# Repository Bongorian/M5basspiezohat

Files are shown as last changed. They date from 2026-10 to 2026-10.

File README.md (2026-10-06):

# M5basspiezohat

M5StickS3のHat2に接続する、ベース用の5チャンネル・ピエゾ入力基板。弦ごとの独立したピエゾ信号を高入力抵抗のバッファと音声ADCで処理し、TDMで本体へ送る。

本体で音程検出とUSB MIDI出力を行うESP-IDFファームウェアを含む。基板とファームウェアは実機未検証のR1試作版。

```text
独立ピエゾ ×4〜5 → 保護・バッファ・LPF → ES7210 ×2
                                      → TDM → M5StickS3
                                               → 音程検出・USB MIDI
```

## 仕様

| 項目 | R1 |
| --- | --- |
| 接続先 | M5StickS3 Hat2 |
| 入力 | 独立ピエゾ最大5チャンネル、内部SIG/GNDはんだパッド |
| ADC | ES7210×2、TDMカスケード接続 |
| 電源 | Hat2 EXT_5V、基板内でアナログ／デジタル3.3Vを生成 |
| 基板 | 21×38×1.0mm、4層、四隅R1mm |
| 実装 | 表面PCBA 101点。裏面は裸銅箔テストパッド4点 |
| 手実装 | ヘッダJ6、ピエゾ配線 |
| 筐体の設計範囲 | Hat単体・コネクタ込み48×24×15mm以内 |

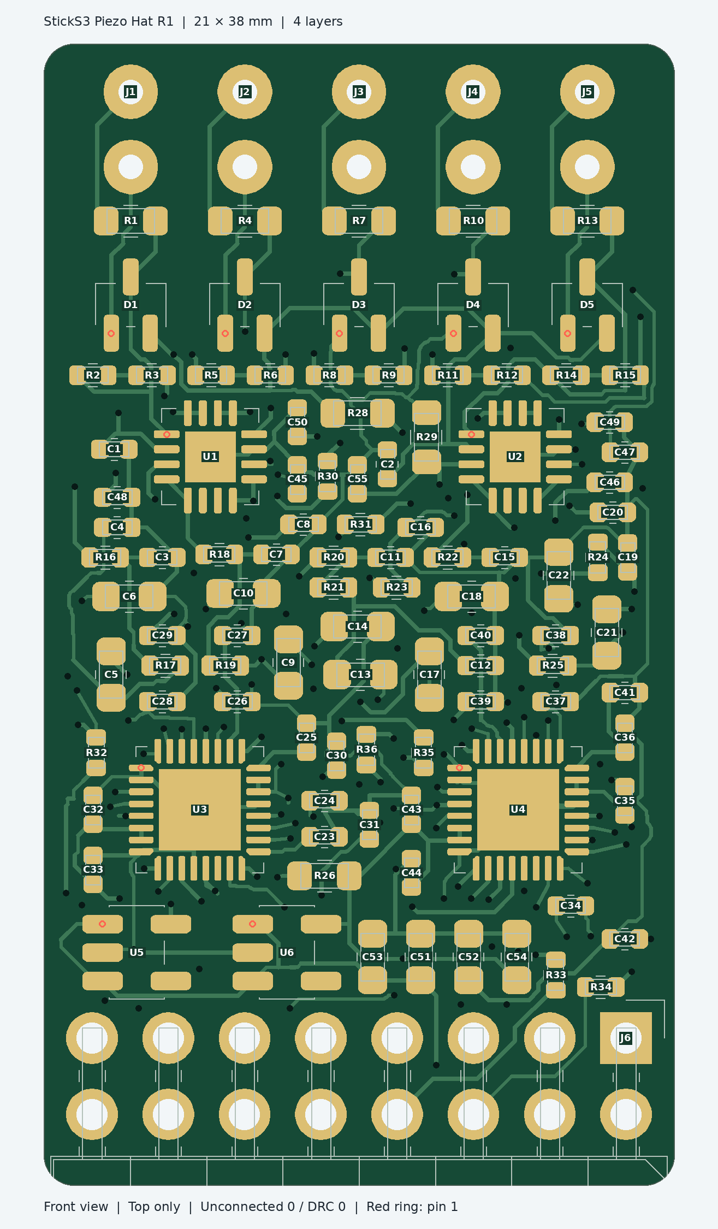
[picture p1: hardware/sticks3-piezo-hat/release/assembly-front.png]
部品位置とピン1


## 設計データの利用

1. [基板仕様・接続表](hardware/sticks3-piezo-hat/README.md)で電源、Hat2端子、ピエゾ入力を確認する。
2. KiCad 9で [プロジェクト](hardware/sticks3-piezo-hat/sticks3-piezo-hat.kicad_pro)を開く。[回路図](hardware/sticks3-piezo-hat/sticks3-piezo-hat.kicad_sch)と[配線済み基板](hardware/sticks3-piezo-hat/sticks3-piezo-hat.kicad_pcb)が編集元。
3. 製造には [JLCPCB用データ一式](hardware/sticks3-piezo-hat/release/PCBA_JLCPCB.zip)と[製造・組立手順](hardware/sticks3-piezo-hat/manufacturing.md)を使用する。BOM、CPL、手実装部品の一覧を含む。
4. 変更後は[再生成・検査手順](hardware/sticks3-piezo-hat/README.md#ソースと再生成)に従い、製造データを再出力する。
5. [ファームウェアの導入・操作手順](firmware/README.md)に従ってM5StickS3へ書き込み、入力スロットを確認する。標準は5弦・共通MIDIチャンネル1・起動時ミュート・高速開始設定。[標準設定の書き込み用ZIP](firmware/release/m5basspiezohat-sticks3-0.2.1.zip)も使用できる。

## 検証状況

KiCad 9.0.9で未接続0件、DRC違反0件、ERC違反0件。回路図・基板・設計マニフェストの318接続を照合済み。[検査記録](hardware/sticks3-piezo-hat/validation.md)を参照。

Hat2ヘッダの嵌合、TDM取得、Low Bまでの周波数応答、弦間の振動漏れ、音程検出の遅延は未検証。[ファームウェア設計・評価手順](docs/firmware-design.md)に取得条件と評価項目を記載している。標準のUSBデバイスモードはUSBホストへ接続する。ホストモードも実装しているが、StickS3はUSB-Cへ給電しないため、音源側への外部VBUS給電と適切な接続回路が必要。

ファームウェアはESP-IDF v5.4.2でESP32-S3向けビルドを確認。合成信号による音程・発音・MIDIルーティングのホストテストを通過している。[CI](https://github.com/Bongorian/M5basspiezohat/actions/workflows/firmware.yml)でもビルドとテストを実行する。

[クロストーク分離・校正学習の検討](docs/crosstalk-separation.md)には固定行列とFIR分離の導入条件を記載。同期CSVから固定混合行列を学習するオフライン評価ツールを含む。リアルタイム分離と実機学習は未実装。

[Grove接続の外付けUSB MIDIホスト案](docs/grove-usb-midi-host.md)に、別USB端子を追加して本体USB-Cを維持する構成、通信・給電条件、LCSC部品候補を記載している。外部基板は未製作。

[筐体モデル](mechanical/sticks3-hat-concept.md)は寸法・保持構造の検討用。蓋と下端受けの固定方法、ケーブル出口は未設計。

## ファイル構成

| ディレクトリ | 内容 |
| --- | --- |
| `hardware/sticks3-piezo-hat/` | KiCad編集元、プロジェクト内ライブラリ、BOM、生成・検査ツール |
| `hardware/sticks3-piezo-hat/release/` | Gerber、PCBA用BOM/CPL、組立位置図、製造用ZIP |
| `mechanical/` | Blender筐体検討モデル、寸法計算、生成スクリプト |
| `docs/` | ファームウェア設計と評価手順 |
| `firmware/` | ESP-IDFアプリ、音程検出、USB MIDI、診断ツール、ホストテスト、書き込み用ZIP |

## ライセンス

KiCad由来のライブラリ・モデルとファームウェア依存ライブラリの出典・ライセンスは [NOTICE.md](NOTICE.md) を参照。プロジェクト独自部分の利用ライセンスは未指定。

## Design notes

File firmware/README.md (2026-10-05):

# M5StickS3 firmware

M5basspiezohat R1の5入力をES7210×2からTDM/DMAで取得し、弦別の音程をUSB MIDI 1.0へ変換するESP-IDFアプリケーション。M5StickS3専用。実機でのADCカスケード取得・音源発音・処理速度は未検証。

## 実装内容

- 16kHz、8スロット、16bitのTDM受信。32フレーム単位、DMA 8バッファ。
- ES7210のI²C初期化、チップID・設定・動作状態の読み戻し。
- 4／5弦の独立解析。DC除去、63タップFIR、4kHzへの間引き、YIN音程推定。
- Note On／Off、入力強度に応じたVelocity、再ピッキング。弦別チャンネル時は任意で±2半音Pitch Bend。
- USB MIDIとUSB CDC診断の複合デバイス。液晶表示、ボタン操作、入力スロット変更。
- USB MIDIホスト送信。モードをNVSへ保存し、再起動でデバイス／ホストを切り替える。
- USB再接続、DMA欠損、送信キュー不足時のAll Sound Offと解析履歴のクリア。
- 発音開始は短い観測＋4ms更新、持続音は長い観測＋8ms更新。弦ごとの判定時刻を分散し、USBホストでは複数イベントをまとめて送信する。

## 標準設定

| 項目 | 値 |
| --- | --- |
| 本体 | M5StickS3、ESP32-S3、Flash 8MB／OPI PSRAM 8MB |
| ピエゾ入力 | J1〜J5 = B0／E1／A1／D2／G2、MIDIノート23／28／33／38／43 |
| TDM | DSP A、1 BCLK幅WS、1 bit遅延、8×16bit |
| クロック計算値 | MCLK 4.096MHz、BCLK 2.048MHz、WS 16kHz |
| 入力スロット | J1〜J5 = 0〜4。実基板で確認・修正が必要 |
| ADC PGA | 0dB |
| 発音／停止ゲート | 正規化RMS 0.004／0.002 |
| MIDI | 全弦をチャンネル1へ送信、Pitch Bendなし |
| 起動 | ミュート。確認後に `arm` またはAボタンで発音開始 |
| 音程追従 | 高速開始設定を有効。持続音は長い観測へ戻す |

USB-Cは標準でMIDI**デバイス**として動作する。PC、USB MIDIホスト、USBホスト端子のある音源へ接続する。通常のUSBデバイス端子だけを持つ音源へ接続する場合は、後述のホストモードと外部VBUS給電を使用できる。DIN MIDI出力は搭載していない。デバイスモードのUSB VID/PIDは開発用設定 `303A:4001`。

## USBホスト／デバイス切り替え

`role host` またはBボタン2秒長押しでミュートし、設定保存後に再起動する。B長押しは現在の役割を反転する。次回起動でも保存したモードを使う。デバイスモードでは `role device` も指定できる。モード切り替えはホットスワップではない。

**StickS3本体はUSB-CへVBUSを供給しない。** 本体回路図のUSB電源は入力経路で、固定したM5Unified v0.2.25の `setUsbOutput` はStickS3では動作しない。ホストモードには、音源のUSB端子へ5Vを供給し、StickS3側への逆流を防止できる外部給電アダプタなどの適切な接続回路が必要。電源をつないだだけのYケーブルや、動作が不明なハブは前提にしない。本体と音源の電源条件、Type-Cの役割・CC条件も接続機器に合わせて確認する。ソフトウェアのホスト切り替えだけでバス給電型音源へ直結できることを意味しない。[本体資料・回路図](https://docs.m5stack.com/en/core/StickS3#schematics)

公開回路図ではCC1／CC2に5.1kΩの固定プルダウン（R3／R4）がある。ファームウェアはこの抵抗を切り替えられず、USB-CのDRP／電力役割の切り替えは実装しない。ホストPHYで通信できることと、Type-Cポートが適切なホスト接続を構成できることを分けて評価する。外部接続回路はVBUSだけでなくCC条件も満たす必要があり、一般的なUSB-Cケーブルでの音源直結は保証しない。

ホストはFull-Speedのクラス準拠USB MIDI 1.0、最初の設定のalternate setting 0、最初の対応するbulk OUT、cable 0へ送信する。複合デバイス内のMIDIインターフェースにも対応する。MIDI 2.0専用、独自ドライバ必須、複数音源・ハブ、多ケーブル選択、MIDI受信は対象外。MIDI端子のあるUSB音源・USB MIDIインターフェースを外部デバイスとして接続する。[ESP-IDFホスト仕様](https://docs.espressif.com/projects/esp-idf/en/v5.4.2/esp32s3/api-reference/peripherals/usb_host.html)

ホストモード中は同じUSB-CでPCへCDC診断を提供できない。LCDに `HOST` と接続状態を表示する。Aクリックで発音切替、Aを1秒長押しで固定ノート試験、BクリックでPanic、Bを2秒長押しでデバイスモードへ戻る。USBは対応音源の列挙・初期Panic完了後に `ready` となる。

復旧時はAを押したままリセットすると、その起動を強制デバイスモードにできる。保存モードは変更しないため、CDCから `role device` で保存する。書き込みが必要なら本体のROMダウンロードモードを使う。PCへの接続前にデバイスモードへ戻す。

切断・再接続で解析状態をクリアする。転送異常や1秒以上応答しない音源では送信を停止し、再接続を要求する。ケーブル断や応答不能で届かないNote Offはソフトウェアで保証できないため、音源側の停止操作も利用する。ホストの給電と実機の列挙・発音は未検証。

## ビルド

LinuxでGit、Python 3、CMake、NinjaとESP-IDFの[インストール前提パッケージ](https://docs.espressif.com/projects/esp-idf/en/v5.4.2/esp32s3/get-started/linux-macos-setup.html)を用意する。リポジトリのルートから実行する。

```sh
bash firmware/tools/setup.sh
bash firmware/tools/build.sh
```

既にESP-IDF v5.4.2がある場合は、その `export.sh` を読み込んでから `build.sh` を実行できる。ローカルの `firmware/.tools/esp-idf` がある場合はそちらが優先される。setupはSDKのコミットを検査する。ライブラリの版と取得ハッシュは `main/idf_component.yml` と `dependencies.lock` に固定している。

```sh
bash firmware/tools/build.sh menuconfig
```

`M5basspiezohat` メニューで弦数、スロット、ゲート、PGA、MIDIチャンネル、弦別チャンネル、Pitch Bend、起動ミュート、TDM形式を設定する。4弦設定はJ1〜J4=E1／A1／D2／G2。弦別チャンネルは基本チャンネルから連続して使用し、最後が16を超える設定では発音しない。スロット重複、停止ゲート以上に低い発音ゲートも無効設定となる。

`Short startup observation and 4 ms initial pitch update`（`CONFIG_BASS_FAST_TRACKING`）は標準で有効。無効にすると発音開始から長い観測＋8ms更新を使う。どちらも確信度0.85と2回の安定判定を維持する。計算処理の最適化は両設定で有効。比較値と実機での確認条件は [処理時間と発音遅延](performance.md) を参照。

TDM形式のPhilipsはカスケード評価用の別設定。スロットの並びも変わり得るため、形式を変更したら全入力を再確認する。任意のチューニングは `main/board.hpp` の `open_notes` を変更する。

## 書き込み

書き込みは既存の本体ファームウェアとパーティションテーブルを置き換える。M5StickS3をUSBでPCへ接続し、OSが割り当てたポートに置き換える。

```sh
bash firmware/tools/build.sh -p /dev/ttyACM0 flash
```

接続できない場合は本体のダウンロードモードへ入れて再試行する。起動後は複合USBデバイスへ切り替わるため、CDCポート番号が変わる場合がある。[本体の公式資料](https://docs.m5stack.com/en/core/StickS3)も参照。

`release/m5basspiezohat-sticks3-0.2.1.zip` は高速開始設定を含む標準設定でのビルド済みファームウェア。0.1.0と0.2.0のZIPも比較用に保持する。展開先でPython環境に `esptool==4.9.0` を導入し、次のように書き込める。ブートローダ、パーティション、アプリをそれぞれ指定し、NVS領域の一括消去は行わない。

```sh
python -m esptool --chip esp32s3 --port /dev/ttyACM0 --baud 460800 write_flash \
  --flash_mode dio --flash_freq 80m --flash_size 8MB \
  0x0 bootloader/bootloader.bin \
  0x8000 partition_table/partition-table.bin \
  0x10000 m5basspiezohat.bin
```

ビルド済みZIPの `BUILD_INFO.json` にSDK・設定・SHA-256を記録している。自前ビルドのパッケージ化は `python3 firmware/tools/package.py`。

## 初回確認

1. 電源を切ってHat2とピエゾを接続する。[接続表](../hardware/sticks3-piezo-hat/README.md#hat2接続)に従う。
2. USBで起動し、LCDの `MUTED` とADC状態を確認する。ADC異常時もUSB診断と固定ノート試験は使用できる。
3. USB MIDIホスト側で `M5basspiezohat R1` を選び、音源をMIDIチャンネル1に設定する。
4. CDC端末から `test` を送る。ノート36、Velocity 80を300ms発音し、ピエゾからの発音はミュートする。
5. `slots` を観測し、J1〜J5へ順番に既知の信号を入力する。各入力に対応する0〜7のスロットを特定する。ピエゾ弦間の機械的漏れがある場合は、入力パッドへの電気信号で確認する。
6. 例えば対応が6／3／0／7／2なら `map 6 3 0 7 2`。続けて `status` で反映を確認する。`map` はミュートする。変更はRAM上のみなので、常用値はmenuconfigへ保存して再ビルドする。
7. `arm` またはAボタンで発音を開始する。無音でNote Off、各弦の開放音、同時発音を確認する。Aでミュート切替、BでミュートとPanic。

標準の共通チャンネルでは、複数弦の同じノートを1音として保持し、最後の弦が停止したときにNote Offを送る。その間の同じ音の再アタックは統合される。弦ごとの同音再発音やPitch Bendが必要なら、弦別チャンネルを有効にし、音源の受信チャンネルを揃える。Pitch Bend時はRPNで±2半音を設定する。

## 診断

CDCは115200設定の改行区切りASCIIコマンド。USB MIDIと同時に利用できる。Python補助ツールは `python3 -m pip install -r firmware/tools/requirements.txt` で依存を導入する。

```sh
python3 firmware/tools/console.py /dev/ttyACM0 status
python3 firmware/tools/console.py /dev/ttyACM0 slots --watch
python3 firmware/tools/console.py /dev/ttyACM0 map 6 3 0 7 2
python3 firmware/tools/console.py /dev/ttyACM0 arm
```

| コマンド | 内容 |
| --- | --- |
| `help` | コマンド一覧 |
| `status` | ADC／USB状態、ミュート、欠損、最大DSP処理時間、空きRAM、弦別音程・確信度・クリップ数 |
| `slots` | 全8スロットのRMSと直近ブロックのピーク |
| `adc` | 両ADCの主要レジスタ読み戻し |
| `map S1 S2 S3 S4 [S5]` | J1から順にスロットを指定。重複不可 |
| `arm` | ADCと設定が正常なら発音開始 |
| `mute`／`panic` | 発音停止とAll Sound Off／All Notes Off |
| `test` | 設定した基本チャンネルで固定ノート36を発音。A長押しでも実行 |
| `role [host\|device]` | USB役割の確認／NVS保存と再起動 |

`dma_ovf`、`queue_drop`、`read_err`、`midi_drop`、`gaps` が増加しないことを確認する。`queue_peak` は取得キューからブロックを取り出した直後の最大待ちブロック数で、1ブロックは2ms。最大処理時間だけで平均負荷は判断しない。`dsp_us`／`max_dsp_us` は音程処理とスロット診断の経過時間を測り、タスクの割り込みを含み得る。共有状態の更新・USB・LCDの時間は含まない。`dsp_us` の増分を観測時間と比較し、10分以上の連続取得で欠損を調べる。状態の公開は16msごと。`clips` が増える場合はPGAを下げ、入力振幅と前段回路を確認する。

## 検証と制約

ホストテストは合成信号を使用し、Low B〜G4、倍音優勢波形、5入力同時検出、無音、DC、ノイズ、クリップ、任意サイズの受信ブロック、Velocity、Pitch Bend、再ピッキング、スロット変更、送信失敗、同音の共有とチャンネル割り当てを確認する。

```sh
cmake -S firmware/tests -B firmware/build-host -G Ninja
cmake --build firmware/build-host
ctest --test-dir firmware/build-host --output-on-failure
```

標準でAddressSanitizer／UndefinedBehaviorSanitizerを有効にする。GitHub ActionsでもホストテストとESP32-S3ビルドを実行する。

標準設定の合成開放音では、入力開始から最初のNote OnまでB0=64ms、E1=48ms、A1=40ms、D2=32ms、G2=28ms分のサンプルを使用した。これは各弦を単独の1入力設定で評価した結果で、5入力時は弦ごとに判定位相が異なる。ADC・USB・音源遅延と実機のCPU処理時間を含まない。演奏時の遅延保証ではない。

実機ではADCのリビジョン、8スロットの出力順、クロック、低域HPF、USBの両役割、CPU余裕、弦間漏れを確認する必要がある。レジスタの読み戻しが成功しても音声フレームの正しさは保証されない。USB役割だけをNVSへ保存し、スロット・ゲート・ゲインはビルド設定で管理する。OTAは実装していない。

弦間クロストークは [分離・校正学習の検討](../docs/crosstalk-separation.md) を参照。同期CSVから固定混合行列を学習するオフライン評価ツールと合成テストを収録している。リアルタイム分離・本体での学習・校正波形のUSB出力は未実装。

詳細は [実装設計・評価手順](../docs/firmware-design.md) と [依存ライブラリの出典](../NOTICE.md) を参照。

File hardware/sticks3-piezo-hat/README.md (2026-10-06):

# M5basspiezohat R1 — 基板仕様

弦ごとに独立したピエゾを最大5入力受け、ES7210×2のTDM出力をM5StickS3へ渡す。[付属ファームウェア](../../firmware/README.md)が音程検出とUSB MIDI出力を行う。基板・ファームウェアとも実機未検証。

**筐体の設計範囲：Hat単体・コネクタ込み48×24×15mm以内。** 基板は21×38×1.0mm、四隅R1mm、4層。ケース本体41.1×23.8×14.8mm。候補ヘッダC53207371のメーカー図面に基づくコネクタ込み公称長47.3mm、公差予算込み47.9mm。実機嵌合・造形精度は未確認で、寸法保証ではない。基板に固定穴・切り欠きはなく、筐体の左右ガイド溝と上下の受けで支える機構案。受けと蓋の留め方は未設計。[機構案](../../mechanical/sticks3-hat-concept.md)を参照。

## 設計検査

KiCad 9.0.9で未接続0件、DRC違反0件、回路図ERC違反0件。配線済み基板は [sticks3-piezo-hat.kicad_pcb](sticks3-piezo-hat.kicad_pcb)。2410配線セグメント／161ビア、回路図／基板／設計マニフェストの318接続が一致。部品本体は表面のみ、裏面はTP1〜4の裸銅箔。内層GND面の信号線は0、SMDパッドとビア穴の重なりは0。

[JLCPCB用データ一式](release/README.md)：[Gerber ZIP](release/Gerber_JLCPCB.zip)、[PCBA BOM](release/BOM_JLCPCB.csv)、[CPL](release/CPL_JLCPCB.csv)、[組立位置図](release/assembly-front.png)。BOMとCPLは101個の部品名が完全一致し、全点Top。CPLは品番別の回転補正を適用済み。D1〜D5もPCBA対象。J6とピエゾ線は手実装。U4の割り込み出力（13番ピン）はNC。ADC初期設定では割り込みを無効にする。

最小配線幅／間隔0.10／0.10mm、貫通ビア外径0.40mm・穴0.20mm、表裏テント、マスク開口1:1。[JLCPCBの能力表](https://jlcpcb.com/capabilities/pcb-capabilities)に対応するが、外径0.45mm未満・穴0.20mmのビアは追加料金対象なので、注文時に小径ビアの条件を指定する。製造条件と手実装の手順は [manufacturing.md](manufacturing.md)、検査記録は [validation.md](validation.md) を参照。

## 回路

| 回路 | 仕様 |
| --- | --- |
| 入力 | SIG/GND ×5組、内部はんだパッド、穴0.8mm・径1.8mm |
| 保護 | 47kΩ直列＋低漏れBAV199Wの2ダイオードクランプ |
| 入力負荷 | 10MΩを2個直列にした20MΩでVMIDへバイアス |
| バッファ | TLV9064IRTER ×2、3×3mm WQFN、利得1 |
| 中点 | 47kΩ分圧＋1µF→U2Bバッファ、約1.65V |
| LPF | 各入力1kΩ／47nFを2段、受動回路 |
| ADC結合 | P側10µF直列、N側10µFでAC接地。ADCのDCバイアスを分離 |
| ADC | ES7210 ×2、入力8スロット、うち5スロットを音程解析 |
| 電源 | EXT_5V→AP2112K-3.3 ×2、3V3A／3V3D |
| クロック | MCLK/BCLK/WSに33Ω、データ／カスケードにも33Ω |

受動LPFは2段の間にバッファがないため、独立したRCを2個掛けた特性と異なる。ADC入力負荷を無視した等しいR/Cの伝達は `1/(1+3sRC+(sRC)^2)`、合成-3dB周波数は約1.27kHz。R=1kΩ、C=47nFによる計算値で、ADC入力インピーダンスを含む実際の応答は測定する。アタックと倍音を残せるか、ADC内PGA・HPFと合わせて確認する。

Low B・30.87Hzを保つため、ピエゾ容量、20MΩ負荷、AC結合容量、ADC内部HPFをまとめて評価する。低漏れ保護の代わりに汎用BAV99や漏れの大きいSchottkyへ無確認で置き換えない。高抵抗入力付近は組み立て後にフラックスを清掃する。無給電時のピエゾ電圧による電源への回り込みも試験する。

## LCSC部品と実装分担

| 部品 | LCSC | 個数 | 分担 |
| --- | --- | ---: | --- |
| ES7210・4入力ADC | [C365743](https://www.lcsc.com/product-detail/C365743.html) | 2 | PCBA |
| TLV9064IRTER・3×3mm WQFN | [C882406](https://www.lcsc.com/product-detail/C882406.html) | 2 | PCBA |
| AP2112K-3.3TRG1 | [C51118](https://www.lcsc.com/product-detail/C51118.html) | 2 | PCBA |
| BAV199W・CBI・SOT-323 | [C51315120](https://www.lcsc.com/product-detail/C51315120.html) | 5 | PCBA |
| 10MΩ・SAE・0402 | [C54531017](https://www.lcsc.com/product-detail/C54531017.html) | 10 | PCBA |
| 1kΩ・0402 | [C11702](https://www.lcsc.com/product-detail/C11702.html) | 12 | PCBA |
| 33Ω・0402 | [C25105](https://www.lcsc.com/product-detail/C25105.html) | 5 | PCBA |
| 47kΩ・0603 | [C25819](https://www.lcsc.com/product-detail/C25819.html) | 8 | PCBA |
| 100nF・0402 | [C1525](https://www.lcsc.com/product-detail/C1525.html) | 6 | PCBA |
| 47nF・0402 | [C82219](https://www.lcsc.com/product-detail/C82219.html) | 10 | PCBA |
| 1µF・0402 | [C52923](https://www.lcsc.com/product-detail/C52923.html) | 25 | PCBA |
| 10µF・0603 | [C19702](https://www.lcsc.com/product-detail/C19702.html) | 14 | PCBA |
| 2×8・2.54mm L型ヘッダ・BXCONN | [C53207371](https://www.lcsc.com/product-detail/C53207371.html)・候補、実機嵌合未確認 | 1 | 手はんだ |
| ピエゾ線 | 基板内パッドへ接続 | 5組 | 手はんだ |

部品番号・数量・実装分担は [BOM_full.csv](BOM_full.csv) を基準とする。PCBAには [BOM_JLCPCB.csv](BOM_JLCPCB.csv)、手実装には [HAND_ASSEMBLY.csv](HAND_ASSEMBLY.csv) を使用する。LCSCの販売在庫とJLCPCBの実装用在庫・部品区分・調達価格は個別に確認する。

## Hat2接続

J6番号は **M5の外部Hat2端子表の番号**。M5内部回路図のCN2番号とは異なる。

| J6 | M5信号 | 本基板 |
| ---: | --- | --- |
| 1 | GND | GND |
| 2 | G5 | SCL |
| 3 | EXT_5V | 5V_HAT |
| 4 | G4 | SDA |
| 6 | G6 | WS |
| 7 | G1 | MCLK |
| 8 | G7 | BCLK |
| 9 | G8 | TDM DATA |
| その他 | BOOT/BAT/3V3/5VIN等 | 未接続 |

この番号とGPIOは [M5公式端子表](https://docs.m5stack.com/en/core/StickS3) に基づく。標準ヘッダのピン1マークと本体のGND位置は、選定した部品の視方向と実物で照合する。嵌合と挿入長は実機で確認する。

`M5.begin()`後、`M5.Power.setExtOutput(true)`でEXT_5Vを出力にする。本体GPIOは3.3V。EXT_5Vを出力にした状態で、その端子へ別電源を接続しない。

ADCの7bit I²CアドレスはU3＝0x40、U4＝0x41を想定したAD0/AD1接続。アドレスは実機で確認する。U3 TDMOUT→33Ω→U4 TDMIN、U4 TDMOUT→33Ω→J6 DATA。共通MCLK/BCLK/WSを使う。レジスタ設定は実機試験で確定する。

## 取得・MIDIの初期条件

16kS/s、8スロット×16bit、MCLK4.096MHz、BCLK2.048MHzを評価開始点とする。DMAは32フレーム×8本、合計4096B／16ms容量。2msごとに取得し、解析側へ渡す。詳細は [ファームウェア設計](../../docs/firmware-design.md) を参照。

Low Bの周期は約32.4ms。DMA待ちを短くしても、音程確定に必要な観測時間は残る。音声取得、音程解析、USB送信、音源発音の遅延を分けて測定する。USB MIDIは本体USB-Cを使い、音源のUSBホスト機能またはPC／USB MIDIホストを経由する。DIN出力回路はこのHatには載せていない。

## ソースと再生成

- `sticks3-piezo-hat.kicad_sch`：全ピンを明示した回路図
- `sticks3-piezo-hat.kicad_pcb`：配線済み最終基板
- `sticks3-piezo-hat-placement.kicad_pcb`：再生成用の配置版
- `PiezoHat.pretty/`、`PiezoHat.kicad_sym`：プロジェクト内ライブラリ
- `design.json`：ピン、型番、部品座標
- `BOM_JLCPCB.csv`：PCBA部品のみ、標準4列
- `jlc-rotation-corrections.json`：品番別のCPL回転補正。新しい品番へ変更したらプレビューを再確認
- `BOM_full.csv`、`HAND_ASSEMBLY.csv`：全調達／手実装
- `verify.py`、`verification.json`：接続と実装面の確認
- `preview/routed-front.png`、`preview/routed-board.glb`：最終基板の配線図・3D
- `release/`：Gerber、BOM、CPL、組立位置図、検査記録
- [ケースモデル](../../mechanical/sticks3-hat-concept.md)

KiCad 9.0.9の`kicad-cli`と`pcbnew`を読み込めるPythonが必要。Ubuntuでは`/usr/bin/python3`を使う。生成にはNumPy、図の出力にはPillow、補助ルータにはSciPyとC++17コンパイラを用意する。自動配線には別途`freerouting-cli`が必要。

```sh
cd hardware/sticks3-piezo-hat
/usr/bin/python3 generate.py
kicad-cli sch export netlist --format kicadxml -o schematic.xml sticks3-piezo-hat.kicad_sch
/usr/bin/python3 verify.py sticks3-piezo-hat-placement.kicad_pcb
/usr/bin/python3 route_compact.py sticks3-piezo-hat-placement.kicad_pcb NEW-routed.kicad_pcb
```

再生成は配置・回路図・BOMを上書きし、配線済み基板は別ファイルに保存する。KiCadのDSN出力へは0.127mm標準配線／0.10mm間隔、ビア径0.40mm・穴0.20mmを明示的に反映する。内層1はGND面、内層2は信号。QFN露出パッドの未充填ビアを禁止する。

## 組立・評価

[製造・組立手順](manufacturing.md)に従い、手実装部品とヘッダ方向を確認する。評価では電源・中点電圧、I²Cアドレス、ADC1個のTDM取得、2個のカスケード取得の順に確認する。ピエゾ接続後、Low Bの周波数応答、強いアタックでのクリップ、弦間漏れを測定する。

## 参照資料

メーカー資料：[ES7210レジスタ資料](https://files.waveshare.com/wiki/common/ES7210_DS.pdf)、[TLV9064](https://www.ti.com/lit/ds/symlink/tlv9064.pdf)、[CBI BAV199W](https://datasheet.lcsc.com/datasheet/pdf/08d81ae9ee2012e6b42c6110d851602f.pdf?productCode=C51315120)、[Espressif I²S/TDM/DMA](https://docs.espressif.com/projects/esp-idf/en/stable/esp32s3/api-reference/peripherals/i2s.html)。

## 製造データの再出力

リポジトリルートから実行する。配線済み基板を入力に、DRC／ERC・接続照合後、Gerber・BOM・CPL・ZIP・チェックサムを再出力する：

```sh
cd hardware/sticks3-piezo-hat
/usr/bin/python3 release.py
```

## 補助ルータ

`finish_route.py`用の補助ルータは `hardware/sticks3-piezo-hat/` で次のように構築する。生成・配線ツールは検討用で、毎回DRC／ERCと接続照合を行う。

```sh
mkdir -p .build
g++ -O3 -std=c++17 finish_astar.cpp -o .build/piezo-finish-astar
```

プロジェクト内のKiCad由来ライブラリについては [ライセンス文書](KICAD_LIBRARIES_LICENSE.md) と [出典](../../NOTICE.md) を参照。

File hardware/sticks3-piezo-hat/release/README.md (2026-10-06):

# M5basspiezohat R1 — 製造・組立手順

実機未検証の試作基板。製造データはKiCad 9.0.9で未接続・DRC・ERC各0件、回路図・基板・設計マニフェスト318接続の照合済み。PCBAは101点、全点Top。

## 製造ファイル

`hardware/sticks3-piezo-hat/release/` に次のファイルを格納している。`PCBA_JLCPCB.zip` は製造用データの一式。

| ファイル | 用途 |
| --- | --- |
| `Gerber_JLCPCB.zip` | 4層銅箔、表裏マスク、表面ペースト、表裏シルク、外形、PTH／NPTHドリル、Gerberジョブ |
| `BOM_JLCPCB.csv` | PCBA用のLCSC部品番号・参照名 |
| `CPL_JLCPCB.csv` | 101点の配置座標・回転、単位mm、Topのみ |
| `rotation-audit.csv` | KiCad角度・JLC補正値・補正後角度・基板のピン1座標。座標はCPLと同じmm／左下原点 |
| `assembly-front.png` | 部品位置とピン1の照合図。赤いリングはピン1 |
| `HAND_ASSEMBLY.csv` | 手実装するヘッダ、ピエゾ配線 |
| `BOM_full.csv` | 全部品の数量と実装分担 |
| `manifest.json` | ZIP・BOM・CPL・組立図のSHA-256とファイルサイズ |

## 基板条件

| 項目 | 指定値 |
| --- | --- |
| 材質・層数 | FR-4、4層 |
| 外形・厚さ | 21×38mm、1.0mm、四隅R1mm |
| 銅厚 | 外層1oz、内層標準0.5oz |
| 層構成 | F.Cu／In1.Cu（GND）／In2.Cu（信号）／B.Cu |
| マスク・実装面 | 緑、表面PCBA |
| 最小配線幅・間隔 | 0.10mm／0.10mm |
| 外形から銅箔 | 0.5mm以上 |
| ビア | 貫通、外径0.40mm、穴0.20mm、表裏テント |
| マスク開口 | 銅箔パッドと1:1 |

SMDペースト領域とビア穴の重なりは0件。裏面はTP1〜TP4の裸銅箔で、実装部品はない。

JLCPCBでは穴0.20mm・外径0.45mm未満のビアに追加料金条件がある。注文時の [基板能力表](https://jlcpcb.com/capabilities/pcb-capabilities) と小径ビア設定を確認する。小型基板のパネル／治具条件は利用する実装サービスで確認する。

## PCBA発注

1. `Gerber_JLCPCB.zip`を読み込み、外形・4層・厚さ1.0mmと上記の基板条件を確認する。
2. 表面実装を選択し、`BOM_JLCPCB.csv`と`CPL_JLCPCB.csv`を読み込む。
3. 101点の参照名、Top面、LCSC品番、在庫、実装区分、調達価格を確認する。
4. `assembly-front.png`と配置プレビューを比較する。特にU1〜U6のピン1と回転、QFN露出パッドを照合する。
5. `HAND_ASSEMBLY.csv`の部品とピエゾ線を別途準備する。

LCSC販売在庫とJLCPCB実装用在庫は個別に確認する。D1〜D5を含む全SMD部品101点をPCBA対象とする。J6ヘッダとピエゾ線は手実装。D1〜D5のC51315120が部品照合で未登録／調達不可の場合は、欠品のまま確定せずJLCPCBの部品調達を設定する。同名のBAV199Wでもメーカー・内部結線・ピン配列を照合せず置き換えない。

## CPLの回転と実装確認

CPLへKiCadの角度をそのまま転記せず、`jlc-rotation-corrections.json`の品番別補正を適用する。Top面で `JLC角度 = (KiCad角度 + 補正) mod 360`。実装座標と基板上のパッド・配線は変更しない。

| 部品 | KiCad角度 | 補正 | CPL角度 | 基板上の向き（表面） |
| --- | ---: | ---: | ---: | --- |
| U1・U2 / C882406 | 0° | 0° | 0° | ピン1は左上側 |
| U3・U4 / C365743 | 0° | 270° | 270° | ピン1は左上側 |
| U5・U6 / C51118 | 0° | 270° | 270° | 左に3端子、右に2端子。ピン1は左上 |
| D1〜D5 / C51315120 | 90° | 270° | 0° | ピン1＝左下GND、2＝右下3V3A、3＝上のHI入力 |

U3〜U6の補正は旧CPLを読み込んだ配置画像の部品マーク・端子列と基板パッドの比較に基づく。D1〜D5は新規追加のため、SOT-323の基準姿勢に基づく補正を新しいJLCPCBプレビューで確認する。新品番・別メーカーへの置換では同じ補正が適用できるとは限らない。

アップロードには補正済み`CPL_JLCPCB.csv`を使う。`CPL_KiCad.csv`は未補正の検査用で、発注には使わない。新データのJLCPCBプレビュー／DFMはまだ確認していない。`assembly-front.png`の赤いリングは基板の実際の1番パッドを示す。JLCPCBの色付き点だけをピン番号と解釈せず、端子列・メーカーのピン配置と合わせて照合する。[JLCPCBの配置・向きの説明](https://jlcpcb.com/help/article/pcb-assembly-faqs-part-2)

## 手実装と通電前確認

1. PCBA済みのD1〜D5のBAV199W保護ダイオードがすべて実装され、組立図のピン番号と一致することを確認する。
2. J6ヘッダを取り付ける。C53207371の嵌合は未検証のため、M5StickS3実物で向き・挿入長を確認する。
3. J1〜J5のSIG／GNDへ弦別ピエゾ線を接続する。高抵抗入力部のフラックスを清掃し、線材への引張力を筐体側で受ける。
4. GND・EXT_5Vの端子位置、電源短絡、ダイオード方向を確認する。端子番号は外部Hat2端子表を基準にする。
5. 本体初期化後にEXT_5Vを有効化し、3V3A／3V3D・VMIDとI²Cアドレスを測定する。EXT_5Vの出力モードでは同端子へ別電源を接続しない。

## 動作評価

ADC単体取得から2個カスケード取得へ進み、スロット対応、Low Bの低域応答、クリップ回復、弦間漏れを測定する。U4の割り込み出力はNCのため、ADC初期設定で割り込みを無効にする。

音程検出・USB MIDIのESP-IDFファームウェアをリポジトリに収録。ビルドと合成信号テストは確認済み、実機は未検証。[導入・診断手順](https://github.com/Bongorian/M5basspiezohat/tree/main/firmware)に従って書き込み、入力スロットを確認する。標準はUSBデバイスで接続先にUSBホスト機能が必要。USBホストモードも搭載するが、StickS3はUSB-Cへ給電しないため、音源側への外部VBUS給電が必要。筐体モデルは寸法・保持構造の検討用で、固定部とケーブル出口は未設計。

接続表・評価条件は [M5basspiezohatリポジトリ](https://github.com/Bongorian/M5basspiezohat) の基板仕様とファームウェア設計を参照。

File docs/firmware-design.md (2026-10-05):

# ファームウェア実装・評価手順

M5StickS3用ESP-IDFアプリケーションは `firmware/` に収録している。[導入・操作手順](../firmware/README.md)を参照。ESP32-S3ビルドと合成信号のホストテストは確認済み。ADCカスケード、USB接続、演奏遅延、CPU負荷の実機測定は未実施。

## 信号経路

```mermaid
flowchart LR
  P[独立ピエゾ 4〜5入力] --> A[保護・バッファ・LPF・AC結合]
  A --> D[ES7210 ×2]
  D -->|8スロット TDM| M[I²S受信・DMA]
  M --> Q[32フレームの取得キュー]
  Q --> F[DC除去・FIR・4kHz間引き]
  F --> Y[弦別YIN・包絡線・発音状態]
  Y --> R[MIDIチャンネル割り当て]
  R --> U[USB MIDIデバイス]
  U --> H[接続先USBホスト・外部音源]
```

## 電源・クロック・ADC

M5Unified初期化では内蔵音声・IMU・RTCを無効にする。本体がM5StickS3と認識された場合だけ `M5.Power.setExtOutput(true)` でHat2 EXT_5Vを供給する。GPIOは3.3V。出力中のEXT_5Vへ別電源を接続しない。[M5StickS3資料](https://docs.m5stack.com/en/core/StickS3)

| 信号 | GPIO / アドレス |
| --- | --- |
| SDA / SCL | GPIO4 / GPIO5、外部I²Cポート1、100kHz |
| MCLK / BCLK / WS / DATA | GPIO1 / GPIO7 / GPIO6 / GPIO8、I²Sポート0 |
| U3 / U4 | 7bit I²C 0x40 / 0x41 |
| USB | 本体USB-C、ESP32-S3のネイティブUSB |

U3 TDMOUT→33Ω→U4 TDMIN、U4 TDMOUT→33Ω→Hat2 DATA。内蔵PMICのGPIO47／48のI²Cポート0と外部ADCバスは分離している。

I²S受信を有効にしてクロックを供給した後、両ADCのID、リビジョンを読み取り、初期化する。設定の読み戻しと120ms後の状態確認を行い、取得を再開して起動直後の64ブロックを破棄する。ADC異常時は取得タスクを開始せず、表示・USB診断・固定ノート試験を維持する。

### 主なADC評価設定

完全な設定表は [es7210.cpp](../firmware/main/es7210.cpp)。以下はES7210 Rev.21資料を基にしたカスケード評価設定で、実機のリビジョンと音声フレームを照合する必要がある。

| レジスタ | 値 / 用途 |
| --- | --- |
| 0x02 / 0x03 / 0x04 / 0x05 / 0x07 | C1 / 02 / 01 / 00 / 20、16kHz・256fs |
| 0x08 | 44、8入力・スレーブ・EQバイパス |
| 0x11 | 63、16bit DSP A。Philips選択時60 |
| 0x12 | U3=07、U4=03、カスケード・最終段指定 |
| 0x0C / 0x10 / 0x16 | 00、割り込み・DMIC・ALCを無効化 |
| 0x20〜0x23 | 0D、低速HPFと自動オフセット補正の評価値 |
| 0x43〜0x46 | 10＋PGA設定、初期0dB |
| 0x4B / 0x4C | 40、ADC/PGA有効、未使用MICBIAS停止 |

[ES7210 Rev.21資料](https://files.waveshare.com/wiki/common/ES7210_DS.pdf)、[EspressifのTDM例](https://github.com/espressif/esp-idf/blob/v5.4.2/examples/peripherals/i2s/i2s_codec/i2s_es7210_tdm/main/i2s_es7210_record_example.c)を参照。設定レジスタが読み戻せることと、カスケード音声が正しく整列することは別に検証する。入力パッドへ既知の周波数を順に与え、全8スロットを観測してJ1〜J5への対応を確定する。

## 取得・タスク

| 項目 | 実装値 |
| --- | ---: |
| 取得レート | 16kS/s |
| フレーム | 8スロット×16bit |
| クロック計算値 | BCLK 2.048MHz、MCLK 4.096MHz |
| 取得ブロック | 32フレーム、512B、2ms |
| DMA | 8バッファ、4096B、16ms容量 |
| 取得→解析キュー | 16ブロック、約8kB、最大32ms分 |
| MIDIイベントキュー | 128イベント |
| USB / 取得 / 解析タスク | Core0優先度6 / Core0優先度22 / Core1優先度17 |
| 表示 | 主タスク、200ms周期 |

DMA容量16msはブロック待ち時間2msとは異なる。取得キューは処理時間の変動を吸収するが、遅延を一定に保証しない。DMAオーバーフロー、取得エラー、ブロック連番の欠損、送信不足ではPanicを要求し、音程履歴・ノート所有情報をクリアする。USBの再接続時も設定チャンネルにCC120／123とPitch Bend中央値を送り、必要時だけRPNで±2半音を設定する。

受信タスクは解析を行わず、ブロックのコピーと連番を管理する。音程処理は取得とは別Coreで行う。USBのFIFO不足は4byteのMIDIパケットを保持して再送し、Panic前の古いイベントは世代番号で捨てる。ISRのオーバーフロー数はFreeRTOSのクリティカルセクションで保護する。[ESP-IDF I²S仕様](https://docs.espressif.com/projects/esp-idf/en/v5.4.2/esp32s3/api-reference/peripherals/i2s.html)

USBはNVSに保存した役割を起動時に読み込む。デバイスモードはTinyUSBのMIDI＋CDC、ホストモードはESP-IDF USB Host Libraryと専用MIDI OUTクライアントを使用する。同じ内蔵PHYへ両方のドライバを同時に入れず、役割変更時はミュートして保存・再起動する。Aを押したままリセットするとその起動だけデバイスモードを強制する。

ホストのライブラリ処理はCore0優先度5の別タスク。全クライアントAPIと転送完了処理は既存のUSB送信タスクで実行する。Full-Speed MIDI 1.0のalternate setting 0、最初のbulk OUT、cable 0を選ぶ。非対応記述子・不正長・MIDI 2.0専用インターフェースは拒否する。非同期転送を1件ずつ処理し、1秒のソフトウェア監視で無応答を停止・キャンセルする。切断時は完了コールバックを待ってから転送・インターフェース・デバイスを解放する。

USBホストでは4byteイベントをendpointの最大パケット長（最大64byte）までまとめ、USB送信タスクの巡回末尾で1転送として送る。別の転送が実行中なら次のバッチを保持する。バッチが満杯なら元のイベントを待たせ、順序を保持する。Panic／切断時は未送信バッチを破棄する。バッチ化はUSBホストの実機転送では未検証。

StickS3はUSB-CへVBUSを供給しないため、ホストでは外部の給電・逆流防止・Type-C役割条件を満たす接続が必要。ホスト時のCDCは提供しない。操作・制限は [USB切り替え手順](../firmware/README.md#usbホストデバイス切り替え) を参照。[USB MIDI 1.0仕様](https://www.usb.org/sites/default/files/midi10.pdf)、[ESP-IDFホストAPI](https://docs.espressif.com/projects/esp-idf/en/v5.4.2/esp32s3/api-reference/peripherals/usb_host.html)

外部音源との接続は、自己給電のクラス準拠USB MIDI音源と本体USBホストモードを基本構成とする。追加のUSBホストマイコンは不要。自己給電は音源の動作用電力をUSBから供給しないという条件であり、USB接続検出用VBUSやType-CのCC条件を省略できることを意味しない。接続回路でこれらを満たし、対象音源で列挙・Note On／Off・切断復帰を確認する。自己給電デバイスのVBUS監視については [EspressifのUSBデバイス仕様](https://docs.espressif.com/projects/esp-idf/en/v5.0.3/esp32s3/api-reference/peripherals/usb_device.html) を参照。

## 音程・発音

入力別DC除去（係数0.9995）→63タップHamming FIR（カットオフ900Hz）→4分の1間引きで4kHzへ変換する。履歴は384サンプル。標準では発音開始時に16サンプル＝4ms周期、持続音は32サンプル＝8ms周期でYIN解析を行う。弦ごとに解析時刻を分散する。FIRは対称係数のペア加算で乗算を63回から32回へ削減し、鏡像リングで内側のループから折り返し処理を除く。

発音開始の比較幅は `max(32, ceil(max_lag/2))`、持続音の比較幅は `max(64, ceil(3*max_lag/4))`。YINは最初のしきい値を満たす谷と補間用の隣接点まで計算する。探索範囲を初期化時に計算する。履歴も鏡像リングに保持し、コピーせず連続領域を直接読む。差分の二乗和は4本の独立した加算で計算する。解析時刻の32bitマスク、設定の検証結果、Velocityの基準値を設定変更時に計算し、処理ループ内の繰り返し計算を省く。包絡線評価は4kHzとし、平滑係数は4サンプル分に合わせる。ミュート／USB未接続時はレベル・クリップを監視し、FIRと音程判定を省略する。復帰時は観測を新しく開始する。取得ブロックは32フレーム＝2msのまま、共有診断状態は16msごとに公開する。

弦の開放音−1半音〜＋25半音を探索範囲とする。YIN確信度0.85以上、2回の安定判定とRMSゲートでNote Onを生成する。Note変更には0.65半音のヒステリシスを適用する。ゲート以下30ms、または確信度不足120msで停止する。RMSから対数スケールのVelocityを求める。同じノートの再ピッキングは包絡線の上昇比3と100msの間隔で検出する。判定パラメータは合成信号での評価値。

標準は共通MIDIチャンネル1。弦別ノート所有情報と参照数で同音のNote Offを管理する。任意の弦別チャンネル設定ではチャンネルを連続割り当てし、Pitch Bendを個別送信できる。受信音源も各チャンネルに対応する必要がある。

合成開放音の最初のNote Onまでのサンプル時間はB0=64ms、E1=48ms、A1=40ms、D2=32ms、G2=28ms。各弦を1入力設定で評価した値。ADCフィルタ・USB・音源遅延と実機のCPU時間を含まない。[比較値と測定条件](../firmware/performance.md) を参照。

## 実機評価

| 段階 | 確認項目 |
| --- | --- |
| 電源・接続 | ヘッダ方向、EXT_5V、3V3A／3V3D、VMID、I²Cアドレス |
| USB | MIDIとCDCの認識、`test` による固定ノート発音、切断・再接続 |
| クロック・ADC | MCLK／BCLK／WS、8スロット、形式、実レート、入力順、再起動時の再現性 |
| 低域 | 前段・AC結合・ADC HPFを含む10〜100Hz応答、Low B=30.87Hzの減衰 |
| 入力範囲 | 最大アタックとクリップ、弱音とゲート、過負荷後の回復、無給電時の回り込み |
| 同期 | 同じ信号を両ADCへ与え、固定遅延とチャンネルずれを測定 |
| DMA・CPU | 10分以上の5入力取得、表示・USB同時使用、欠損、最大・平均処理時間、空きRAM |
| 演奏 | 遅延の中央値・95パーセンタイル、オクターブ誤り、余分なNote On、弦間漏れ、再ピッキング |

前段は20MΩ入力バイアス、TLV9064利得1、1kΩ／47nFの2段LPF、10µF AC結合。ピエゾ容量と負荷抵抗も低域応答に影響する。Cp=1nF、R=20MΩの簡略モデルではカットオフ約7.96Hzだが、ADC入力抵抗・実効容量・HPFを合わせて測定する。[TIピエゾ信号調整](https://www.ti.com/lit/an/sloa033a/sloa033a.pdf)

試験は標準の起動ミュートから開始し、全入力のスロット対応を確認してから発音を有効にする。ソフトウェアは電気的信号の音程を解析するため、ブリッジでの機械的な弦間漏れを自動分離しない。実機評価で設定・回路を変更した場合は、ビルド、テスト、基板検査、製造データを更新する。

分離の導入順序、校正録音、付属のオフライン学習ツールは [クロストーク分離・校正学習](crosstalk-separation.md) を参照。

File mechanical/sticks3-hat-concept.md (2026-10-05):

# R1筐体検討モデル

M5StickS3 Hat2用基板の寸法と外周保持を検討するBlenderモデル。設計範囲はHat単体・コネクタ込み48×24×15mm以内。蓋・下端受けの固定方法とケーブル出口は未設計で、モデルをそのまま製造用筐体として使用できない。

## 寸法

| 項目 | 設計値 |
| --- | --- |
| 基板 | 21×38×1.0mm、4層、四隅R1mm |
| ケース本体 | 長さ41.1×幅23.8×厚さ14.8mm |
| コネクタ込み公称値 | 長さ47.3×幅23.8×厚さ14.8mm |
| 長さの公差予算 | 47.9mm |
| 汎用3Dモデルによるコネクタ込み値 | 長さ46.98×幅23.8×厚さ14.8mm |
| 側壁・背壁 | 1.1mm |
| 内幅・基板の隙間 | 内幅21.6mm、左右各0.3mm |
| Hat2ヘッダ | BXCONN PZ-2.54-2*08-8.5-WZ／C53207371、嵌合未検証 |
| ピエゾパッド | SIG/GND×5組、穴0.8mm、銅箔径1.8mm、各組の穴間2.5mm |

ヘッダの [メーカー図面掲載ページ](https://www.lcsc.com/product-detail/C53207371.html)にある6.9±0.2mm＋6.0±0.2mmを使用した公称長は47.3mm。コネクタ公差+0.4mmとケース・配置公差+0.2mmを加えた設計予算は47.9mm。汎用パッケージモデルの先端は図面より約0.32mm短いため、寸法判定はメーカー図面を基準とする。実機嵌合・造形精度は未検証。

## 基板保持

基板に固定穴・固定用切り欠きはなく、筐体側のガイドと受けで外周を支える構成。

- 左右のガイド溝：幅1.2mm。厚さ1.0mmの基板端を0.3mmの範囲で支える。
- 上端の受け：基板の上方向の移動を制限する。
- 下端の受け：基板を下から差し込んだ後に装着する取り外し式の部品を想定。固定方法は未設計。

部品は表面のみ、テストパッドは裏面の裸銅箔。ヘッダの接点はケース下端から突出する。モデルのIC・ヘッダは汎用パッケージ形状で、製品固有の嵌合保証を含まない。

## 組立時の確認項目

Hat2ヘッダの向き、挿入長、干渉、保持力を実機で確認する。GND／EXT_5V位置は [M5公式端子表](https://docs.m5stack.com/en/core/StickS3)と導通で照合する。内部回路図のCN2番号と外部Hat2端子番号は異なる。

ピエゾ線は上側の穴付きパッドへ接続する。ケース出口の外被固定、接着剤の配置、入力部へ伝わる引張力を評価する。高抵抗入力部はフラックスを清掃する。

## データと再生成

- [寸法検討画像](compact-hat-concept.png)
- [Blenderモデル](compact-hat-concept.blend)
- [寸法計算値](compact-envelope-measurements.json)
- [生成スクリプト](create_compact_concept.py)
- [基板仕様](../hardware/sticks3-piezo-hat/README.md)

Blender 4.5 LTSを使用し、リポジトリルートから実行する。基板GLBを読み込み、モデル・画像・寸法計算値を上書きする。

```sh
blender --background --python-exit-code 1 --python mechanical/create_compact_concept.py
```

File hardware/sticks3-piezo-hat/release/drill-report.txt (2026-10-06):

Drill report for sticks3-piezo-hat.kicad_pcb
Created on 2026-10-06T11:36:13+0900

Copper Layer Stackup:
    =============================================================
    L1 :  F.Cu                      front
    L2 :  In1.Cu                    in1
    L3 :  In2.Cu                    in2
    L4 :  B.Cu                      back

Drill file 'sticks3-piezo-hat-PTH.drl' contains
    plated through holes:
    =============================================================
    T1  0.200mm  0.0079"  (161 holes)
    T2  0.800mm  0.0315"  (10 holes)
    T3  1.020mm  0.0402"  (16 holes)

    Total plated holes count 187

Drill file 'sticks3-piezo-hat-NPTH.drl' contains
    unplated through holes:
    =============================================================

    Total unplated holes count 0

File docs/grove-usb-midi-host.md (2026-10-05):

# Grove接続の外付けUSB MIDIホスト

M5StickS3のUSB-CをUSB MIDIデバイス＋診断CDCのまま維持し、Groveへ独立したUSB MIDIホスト基板を接続する構成案。ピエゾHat R1の回路・配線を変更せず、音源用USB端子と給電制御を外部基板に分離できる。外部基板・Grove送信ファームウェアは未実装。本資料は接続方式と部品候補の調査記録。

基本構成は自己給電音源を本体USBホストモードで使用する方式とする。本構成は、PC接続と外部音源接続を同時に必要とする場合の拡張案であり、基本構成の必須部品ではない。本体USBで必要な接続条件は [ファームウェア設計](firmware-design.md) を参照。

```mermaid
flowchart LR
  P[ピエゾHat] -->|Hat2 TDM| S[M5StickS3 音程検出]
  S -->|本体USB-C| C[PC MIDI・CDC診断]
  S -->|Grove UART| B[外部マイコン USB MIDIホスト]
  B -->|USB-A| M[USB MIDI音源]
  V[5V電源・電流制限] --> B
```

## 接続

StickS3のGroveはGND、5V、GPIO9、GPIO10。[本体PinMap](https://docs.m5stack.com/en/core/StickS3#hy2.0-4p)を参照。コネクタはHY2.0-4P。配線案は以下。

| 線 | 本体 | 外部基板 |
| --- | --- | --- |
| 黒 | GND | GND |
| 赤 | EXT_5V | 電源入力、外部電源からの逆流を防止 |
| 黄 | GPIO9 / UART TX | マイコンUART RX |
| 白 | GPIO10 / UART RX | マイコンUART TX |

信号は3.3V。電源が5VでもGPIOへ5V信号を入れない。外付けマイコンがUSB列挙・MIDIクラス・転送・VBUS給電を担当し、本体は発音イベントと状態確認だけを送る。SPI USBホストICを4線Groveへ直接つなぐ構成ではない。

初期検証はUART 31250baud / 8N1の標準MIDIストリームが使いやすい。3byteのNote Onは線上で0.96ms、5弦分は4.8ms。これはUARTの計算値で、USBとキュー遅延を含まない。Pitch Bendを高頻度で送る場合は帯域を確認する。製品用には高速UART、長さ・連番・CRC付きイベント、送信ACK、相手の接続状態、Panicとハートビートを設ける。1Mbpsで4byteペイロードだけなら40µs、フレームのヘッダ等は別に加算する。

I²C 400kHzも候補だが、USB処理待ちをclock stretchingで本体へ伝えないよう、外部基板内にキューと状態レジスタを設ける。Groveは外部ADCのGPIO4／5とは別系統だが、本体内部バスと合わせてI²Cポート・ドライバの割り当てを確認する。UARTなら既存の内部／外部I²Cを変更せずに済む。

## 候補

| 候補 | 評価 |
| --- | --- |
| RP2040＋USB-A＋保護付き5V | USB Host/Deviceを内蔵。USB MIDIホスト↔UARTの公開実装があるため、試作の第一候補。外付けQSPI Flashが必要 |
| CH32V203C8T6＋USB-A＋保護付き5V | USB Host/DeviceとFlash内蔵。低コスト量産候補。MIDIクラスとUARTプロトコルの実装・検証が必要 |
| Adafruit Feather RP2040 USB Host | USB-Aと5V昇圧・ヒューズを備える開発基板。Grove直結製品ではなく、UARTへの変換配線と専用ファームウェアが必要。56.3mm長でHatの48mm上限を超える |
| M5Stack Module USB / MAX3421E | SPI接続。通常のGroveケーブルだけでは必要信号を確保できない |
| M5Stack Unit MIDI | Grove UARTでDIN MIDIと内蔵音源を扱う。USB MIDIホスト端子はない |

RP2040は [LCSC C2040](https://www.lcsc.com/product-detail/C2040.html)、CH32V203C8T6は [LCSC C3001172](https://www.lcsc.com/product-detail/C3001172.html)で掲載を確認。2026-10-06のページ表示はRP2040が1個約$1.00、CH32V203C8T6が約$0.89。価格・在庫・JLCPCBでのPCBA利用可否は発注時に再確認する。マイコン価格だけでなく、Flash・水晶・USB端子・給電保護・実装費・ファームウェア開発費を含めて比較する。

RP2040のUSB仕様は [Raspberry Pi公式仕様](https://www.raspberrypi.com/products/rp2040/specifications/)。UARTとUSB MIDIを橋渡しする実装例は [midi2usbhost](https://github.com/rppicomidi/midi2usbhost)。CH32V203のUSB機能と評価ソースは [WCH公式リポジトリ](https://github.com/openwch/ch32v20x)。小ピン数品はUSBホストに使う端子が出ているか型番ごとに確認し、シリーズ共通の紹介だけで選ばない。

[Adafruit製品](https://www.adafruit.com/product/5723)はPIOを使った別USB-Aホストを持ち、昇圧と500mAヒューズを備える。試作には参考になるが、5Vの接続先は同基板の電源回路に合わせる。[M5Stack Module USB](https://docs.m5stack.com/en/module/usb)はSPI、[Unit MIDI](https://docs.m5stack.com/en/unit/Unit-MIDI)はUART/DIN。

## 電源・端子

最初はUSB-Aのホスト端子を採用する。USB-Cをホスト用に使う場合はCCのRp、必要な役割・電力制御を外部基板側で実装する。本体USB-Cの固定Rdをソフトウェアで切り替える必要がなくなる。

Grove 5Vは無制限ではない。本体資料の負荷測定は4.88V @ 0.38Aで、これをUSB音源へ500mA供給できる保証として扱わない。ピエゾHatと外部マイコンの消費も測定し、許容範囲を決める。バス給電音源を広く扱うなら、外部基板へ独立した5V入力を設ける。

USB VBUSには電流制限、短絡保護、逆流対策と必要な容量を設ける。外部5VとGrove 5Vを直結せず、外部入力から本体の出力端子へ電流が戻らない構成とする。過電流時はUSB給電を停止し、本体へ異常を報告する。

## ファームウェアの分担

| 本体 | 外部基板 |
| --- | --- |
| ADC/TDM、音程、Velocity、Note状態 | USBデバイスの列挙、MIDI OUT発見、転送 |
| 本体USB MIDI＋CDC | USB VBUS制御、過電流状態 |
| Groveイベント送信、出力先選択 | UART受信キュー、ACK、接続状態返信 |
| 外部切断時のNote状態リセット | UART無通信・リセット・USB再接続時のPanic |

本体USBの役割切り替えに追加して、出力先を `本体USB`／`Groveホスト`／`両方` として管理する構成が考えられる。片側のキュー不足が他方のNote Offを失わせないよう、出力先ごとに状態と再接続世代を管理する。外部基板のUSB・UARTの双方を最初に検証してから、本体の出力先選択を実装する。

USB MIDI音源を鳴らす用途では、外部基板は音程検出を担当せず、高性能なH7級マイコンを必要とする構成ではない。必要なのはUSBホスト機能とMIDIクラスの実装、イベントを保持できるメモリ、確実な給電制御である。

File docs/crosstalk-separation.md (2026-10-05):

# 弦間クロストークの分離・校正学習

5個のピエゾを別チャンネルで取得しても、ブリッジを介して信号が混ざる可能性がある。分離処理を導入する場合は、機械構造・ADC同期・校正データを先に評価する。本資料の分離方式は設計候補であり、実機の分離性能は未測定。付属ファームウェアのリアルタイム経路にはまだ分離係数を適用しない。

## 分離対象

| 現象 | 対応 |
| --- | --- |
| 回路・配線の電気的漏れ | 入力パッドへ既知信号を与え、他入力との比を測定。配線・GND・前段を確認 |
| サドル・ブリッジの機械的伝達 | 単独弦の校正からチャンネル間の振幅・位相・周波数特性を推定 |
| 隣の弦の共鳴 | 隣の弦も実際に振動している。奏者の意図を信号だけから完全に判別できるとは限らない |
| 複数弦を同じ音程で演奏 | 正しい同時演奏。単純な「同じ周波数を検出した弱い入力を消す」規則を適用しない |
| ADC間の固定遅延・スロット誤り | 同一電気信号を両ADCで測り、入力対応と同期を先に修正 |
| ADC／前段のクリップ | 混合後の情報が失われるため、分離で復元しようとせず入力振幅を修正 |

独立ピックアップでも漏れと共鳴は生じ得る。[Laguerre・Scavoneのhexaphonic pickup研究](https://www.dafx.de/paper-archive/2021/proceedings/papers/DAFx20in21_paper_2.pdf)も両者を扱っている。磁気ピックアップの研究結果を、ピエゾブリッジの漏れ率や達成性能として転用しない。

## 推奨する順序

1. **機械構造と実測**：各弦を単独で鳴らし、全入力を同期録音する。弦を押さえていない状態と他弦をミュートした状態の両方を測る。サドル隔離、支持方法、接触圧の変更で漏れが減るか確認する。
2. **固定混合行列**：振幅比と極性が比較的一定なら、4×4／5×5の正則化逆行列を評価する。追加遅延がほぼなく、計算量が少ない。
3. **短いFIR行列**：残留漏れに位相差や周波数依存がある場合、周波数ごとの複素混合特性を学習し、短い因果FIRへ近似する。必要な共通遅延を決める。
4. **発音判定の補助**：分離後の音程、独立したアタック、校正で求めた漏れ上限を組み合わせる。単独信号で説明できない残差信号を本当の別弦の候補として扱う。

初期導入では学習・係数計算をPCで行い、M5StickS3は固定係数の実行に集中する。演奏しながら係数を自動更新すると、同音や倍音が重なる正しい演奏を漏れとして学習し、消してしまう可能性がある。学習は明示した単独弦校正区間に限定する。

## 固定混合行列のモデル

観測を `x=H s+n` とし、Hの列iを「弦iを単独で鳴らしたときの各センサーへの伝達」とする。Hの対角を1とした相対尺度を使う。各単独弦録音のDCを除去し、主入力に対する符号付き最小二乗比を計算する。

```text
H[j,i] = median_over_clips( sum(x_j*x_i) / sum(x_i*x_i) )
W = inverse(H^T H + λ I) H^T
s_est = W x
```

λを増やすと逆行列のノイズ増幅を抑えやすいが、残留漏れと振幅の縮小も増える。完全な復元や正しいVelocityを保証しない。Hがほぼ特異なら、元の弦信号を安定に区別できない。単独の生ピエゾ振幅を真の弦運動として測定できているわけでもないため、校正チャンネルの相対尺度として解釈する。

### 付属のオフライン学習ツール

`firmware/tools/crosstalk.py` はPython標準ライブラリだけで動く評価用ツール。同期16kHz、正規化振幅−1〜1、列名 `J1,J2,J3,J4[,J5]` のCSVを受け取る。CSVは別途取得する。現在の `slots`／`status` は要約値であり、この校正用の同期波形を出力する機能ではない。

校正マニフェスト例：

```json
{
  "sample_rate": 16000,
  "channels": 5,
  "clips": [
    {"string": 1, "file": "B_open_01.csv"},
    {"string": 2, "file": "E_open_01.csv"},
    {"string": 3, "file": "A_open_01.csv"},
    {"string": 4, "file": "D_open_01.csv"},
    {"string": 5, "file": "G_open_01.csv"}
  ]
}
```

`string` はJ番号。各CSVは全4／5入力を含み、鳴らす弦だけを変える。複数録音は `clips` へ追加する。

```sh
python3 firmware/tools/crosstalk.py fit calibration/manifest.json model.json --ridge 0.01
python3 firmware/tools/crosstalk.py apply model.json validation/chord.csv separated.csv
python3 -m unittest discover -s firmware/tests -p 'test_*.py'
```

モデルには混合・分離行列、録音間の係数偏差、条件数、最大行和によるノイズ増幅上限を記録する。各弦の録音がない、振幅不足、クリップ、非有限値、特異行列、条件数30超、ノイズ増幅上限3超の場合は学習を拒否する。閾値とλ=0.01は評価開始値。未知の実機特性に対する保証値ではない。分離出力はクリップせず、増幅や残差を確認できるようにする。

合成テストでは既知の瞬時混合、極性反転、4／5入力、同音の同時演奏、分離不能な混合を確認する。実録音の有効性や周波数依存の分離は確認していない。ツールはモデルを本体へ自動配布しない。

## 校正録音の条件

- ゲイン、サンプルレート、スロット順、弦・ブリッジ取り付けを固定する。
- 各弦で開放・5・12・19フレットを中心に、弱／中／強、指／ピック、複数回のアタックを記録する。録音の一部は学習に使わず検証へ回す。
- 無音区間でノイズ床を測る。強く鳴らしたチャンネルがクリップする録音は使わない。
- 他弦をミュートした学習だけで済ませず、ミュートしない単独弦、実際のコード、同音・オクターブ・5度、弱い別弦のアタックでも評価する。
- アタックと持続部で係数が変わるか、チューニング、弦交換、接触圧、楽器の保持方法でモデルが変わるか調べる。

ピックアップ変換のFIR研究では、学習・評価する音程や弾き方の違いが誤差へ影響した。[Mohamad・Dixon・Harteの研究](https://dafx.de/paper-archive/details/KVQINF232FWbIIXsBVbgVw)を、校正条件を広げる理由として参照する。

## 固定行列で足りない場合

周波数領域で `H[j,i,f]` の複素振幅を推定し、ノイズの大きい周波数を除外しながら正則化する。単一の持続正弦波ではFIR全体を特定しにくいため、複数の音程・アタックを含む録音を使う。推定したWを因果FIR行列へ近似し、先行成分のための共通遅延とフィルタ長を設定する。

実装候補は共通DC除去・LPF・4kHz間引きの後、YINの前へ置く32タップ程度の5×5 FIR。計算量は `5×5×32×4000 = 3.2M MAC/s`、係数・履歴は数kB程度。これは演算回数の計算であり、ESP32-S3でのCPU余裕は未測定。ブロックFFT方式はブロック待ち時間が増えるため、既存の音程観測時間に加えて測定する。

モデルを導入する条件は、未使用の検証録音で漏れ由来の誤Note Onが減り、弱い実音・同音同時演奏・アタックが失われず、P95遅延と取得欠損が悪化しないこと。適用を切り替えて比較できるバイパス、楽器ごとの係数保存、モデル形式・スロット順・ゲインの一致検査を設ける。

単独弦の波形を混合した検証だけでは実楽器の共鳴を再現できない。実演奏の正解ラベルと比較し、必要なら機械構造に戻って改善する。

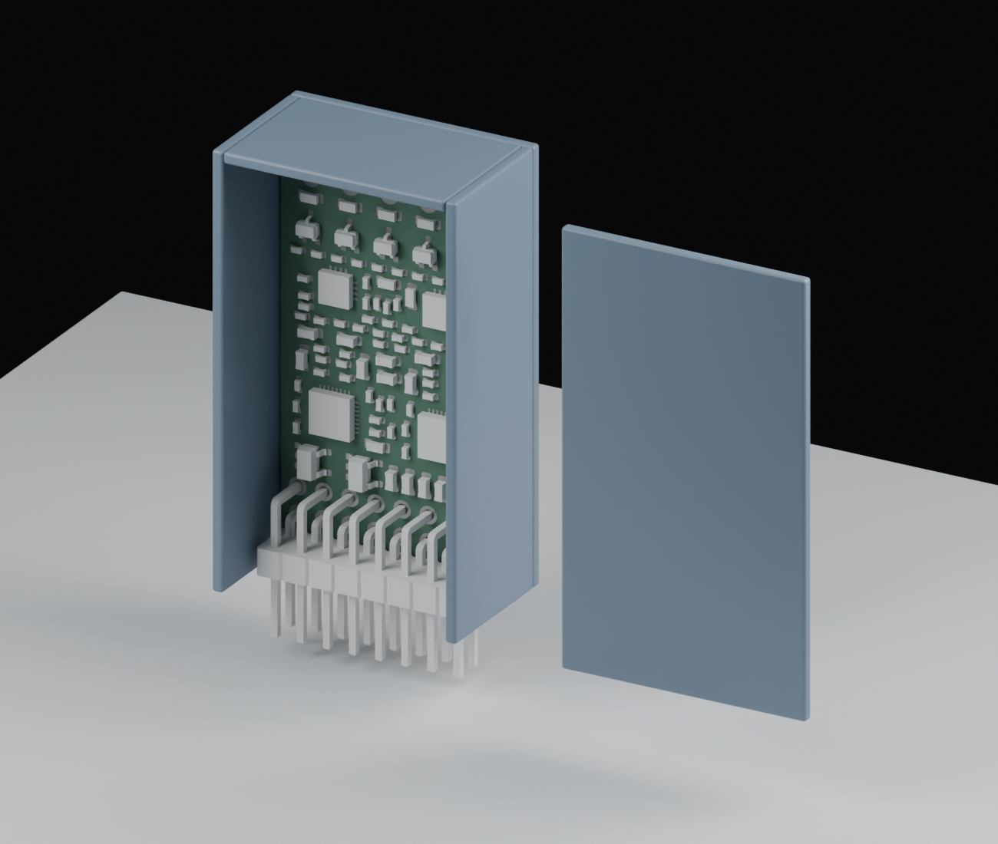
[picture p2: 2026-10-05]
mechanical/compact-hat-concept.png

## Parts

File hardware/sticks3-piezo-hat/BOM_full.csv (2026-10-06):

Comment | Designator | Footprint | LCSC Part # | Quantity | Assembly | Manufacturer Part
PIEZO1 | J1 | PiezoHat:PiezoPair_P3.8 |  | 1 | HAND | Internal wire solder pair
47k | R1,R4,R7,R10,R13,R26,R28,R29 | PiezoHat:R_0603_1608Metric_AssemblyFront | C25819 | 8 | JLC | 0603WAF4702T5E
10M | R2,R3,R5,R6,R8,R9,R11,R12,R14,R15 | PiezoHat:R_0402_1005Metric_AssemblyFront | C54531017 | 10 | JLC | 1RC0402J0106
BAV199W | D1,D2,D3,D4,D5 | PiezoHat:SOT-323_SC-70_AssemblyFront | C51315120 | 5 | JLC | BAV199W (CBI)
PIEZO2 | J2 | PiezoHat:PiezoPair_P3.8 |  | 1 | HAND | Internal wire solder pair
PIEZO3 | J3 | PiezoHat:PiezoPair_P3.8 |  | 1 | HAND | Internal wire solder pair
PIEZO4 | J4 | PiezoHat:PiezoPair_P3.8 |  | 1 | HAND | Internal wire solder pair
PIEZO5 | J5 | PiezoHat:PiezoPair_P3.8 |  | 1 | HAND | Internal wire solder pair
TLV9064IRTER | U1,U2 | PiezoHat:QFN-16-1EP_3x3mm_P0.5mm_EP1.675x1.675mm_AssemblyFront | C882406 | 2 | JLC | TLV9064IRTER
100n | C1,C2,C32,C33,C43,C44 | PiezoHat:C_0402_1005Metric_AssemblyFront | C1525 | 6 | JLC | CL05B104KO5NNNC
1k | R16,R17,R18,R19,R20,R21,R22,R23,R24,R25,R30,R31 | PiezoHat:R_0402_1005Metric_AssemblyFront | C11702 | 12 | JLC | 0402WGF1001TCE
47n | C3,C4,C7,C8,C11,C12,C15,C16,C19,C20 | PiezoHat:C_0402_1005Metric_AssemblyFront | C82219 | 10 | JLC | 0402B473K500NT
10u | C5,C6,C9,C10,C13,C14,C17,C18,C21,C22,C51,C52,C53,C54 | PiezoHat:C_0603_1608Metric_AssemblyFront | C19702 | 14 | JLC | CL10A106KP8NNNC
ES7210 | U3,U4 | PiezoHat:ES7210_QFN32_4x4_P0.4_EP2.7 | C365743 | 2 | JLC | ES7210
1u | C23,C24,C25,C26,C27,C28,C29,C30,C31,C34,C35,C36,C37,C38,C39,C40,C41,C42,C45,C46,C47,C48,C49,C50,C55 | PiezoHat:C_0402_1005Metric_AssemblyFront | C52923 | 25 | JLC | CL05A105KA5NQNC
AP2112K-3.3TRG1 | U5,U6 | PiezoHat:SOT-23-5_AssemblyFront | C51118 | 2 | JLC | AP2112K-3.3TRG1
33R | R32,R33,R34,R35,R36 | PiezoHat:R_0402_1005Metric_AssemblyFront | C25105 | 5 | JLC | 0402WGF330JTCE
HAT2_MANUAL | J6 | PiezoHat:PinHeader_2x08_P2.54mm_Horizontal_AssemblyFront | C53207371 | 1 | HAND | BXCONN PZ-2.54-2*08-8.5-WZ

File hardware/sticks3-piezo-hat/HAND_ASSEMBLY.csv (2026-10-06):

Designator | Part | LCSC | Instructions
J1 | Internal wire solder pair |  | Fit after PCBA; required before powered piezo use
J2 | Internal wire solder pair |  | Fit after PCBA; required before powered piezo use
J3 | Internal wire solder pair |  | Fit after PCBA; required before powered piezo use
J4 | Internal wire solder pair |  | Fit after PCBA; required before powered piezo use
J5 | Internal wire solder pair |  | Fit after PCBA; required before powered piezo use
J6 | BXCONN PZ-2.54-2*08-8.5-WZ | C53207371 | Fit after PCBA; required before powered piezo use

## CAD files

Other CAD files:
mechanical/compact-hat-concept.blend

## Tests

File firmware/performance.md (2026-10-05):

# Processing time and note-on delay

Firmware 0.2.1, 2026-10-06. The standard image enables short startup tracking.
No assembled Hat or M5StickS3 was connected for these measurements.

## Implemented optimizations

| Path | Implementation |
| --- | --- |
| ADC acquisition | Retain 16kHz / eight slots / 32-frame blocks / DMA. No additional capture wait is introduced |
| FIR decimation | Preserve the 63-tap response. Symmetric pairs reduce multiplications from 63 to 32; mirrored ring storage removes inner-loop wrap branches |
| Envelope | Evaluate at 4kHz with smoothing constants matched to four input samples; retain 16kHz DC/power/clip monitoring |
| YIN | Cache string ranges; read mirrored history directly without copying; use four independent squared-difference accumulators; stop at the first threshold trough plus interpolation neighbor |
| Scheduling | Spread the five string estimates across each update interval using cached 32-bit phase masks; no per-sample division/modulo |
| Configuration | Validate once per configuration; cache Velocity reference values instead of repeating validation and logarithms |
| Muted/offline | Monitor levels/clips without FIR or pitch estimation; resume with fresh note/history state |
| Diagnostics | Publish shared state every 16ms rather than locking every 2ms input block. Add `queue_peak` to observe processing backlog |
| USB host | Preserve four-byte MIDI event boundaries and order; batch up to the endpoint capacity (maximum 64 bytes) into one asynchronous OUT transfer |

The runtime DSP path has no dynamic allocation. No `-ffast-math`, platform intrinsics or lossy integer quantization is introduced. The four accumulators change floating-point addition order, so intermediate results are not bit-identical; regression tolerances remain unchanged.
Version 0.2.1 preserves the 0.2.0 observation spans, update intervals and decision thresholds. It adds no pitch algorithm or runtime dependency.
Note Off, Velocity, confidence, same-note ownership, the 100ms re-pick interval and panic semantics remain part of the existing note model.
This optimization does not implement crosstalk separation, runtime tuning UI or calibration recording.

## Startup tracking

The default short comparison span is `max(32, ceil(maximum_lag/2))`, updated every 16 analysis samples (4ms).
Once a note is active, the comparison span is `max(64, ceil(3*maximum_lag/4))`, updated every 32 samples (8ms).
Both paths require confidence >=0.85 and two stable decisions. Sustained notes use the longer observation to reduce transient wrong-note changes.

Disabling `CONFIG_BASS_FAST_TRACKING` uses the longer observation and 8ms update from startup as well.
The filter, cached ranges, early termination, scheduling and host batching optimizations remain active.
This is a timing profile comparison, not an exact recreation of the 0.1.0 implementation.

## Synthetic first Note On

The test uses each open string in a **one-input configuration**, a sine wave of normalized amplitude 0.02, 32-frame input blocks and capture of the engine's sample counter at the event.
Five-input configurations have different per-string analysis phases. Do not interpret this table as five simultaneous measured physical latencies.

| Note | 0.1.0 | 0.2.0 / 0.2.1 short startup | Reduction |
| --- | ---: | ---: | ---: |
| B0 / Low B | 80ms | 64ms | 16ms |
| E1 | 64ms | 48ms | 16ms |
| A1 | 48ms | 40ms | 8ms |
| D2 | 48ms | 32ms | 16ms |
| G2 | 40ms | 28ms | 12ms |

These are input-sample times. ADC analog/digital filters, transport, synthesis and target CPU execution are excluded.
Higher frets on the same string still use a range based on that string's open note; their onset delay is not guaranteed to shrink with pitch.

## Desktop computation benchmark

Measured on Intel Xeon E3-1535M v6, Ubuntu, GCC 13.3.0, C++17 `-O2`, without sanitizers.
Each workload processes five seconds of samples per run, five runs; the table reports median elapsed ns per **input frame**.
One frame contains all eight TDM slots. Waveform construction is outside the measured region.
This benchmark measures the portable engine and sink, not ESP-IDF tasks, slot diagnostics, USB or LCD.
The one-second waveform is repeated, including phase discontinuities; the sustained-Low-B regression test covers false notes at these boundaries.

### Coding-only comparison: 0.2.0 to 0.2.1

Reference: the 0.2.0 core from commit `241932ac2e82f43d9339d24fb73076f44ce7d1d8`. Both versions use the same benchmark source, compiler flags and short-startup configuration. These are fresh comparison runs, separate from the historical runs below.

| Workload | 0.2.0 ns/frame | 0.2.1 ns/frame | Speed ratio |
| --- | ---: | ---: | ---: |
| One Low B string | 113.8 | 40.9 | 2.78× |
| Five open strings | 290.0 | 120.7 | 2.40× |
| Five strings at fret 12 | 190.1 | 88.6 | 2.15× |
| Five strings at fret 24 | 137.2 | 73.0 | 1.88× |
| Five channels of gated noise | 351.4 | 152.5 | 2.30× |
| Five silent channels | 80.8 | 56.5 | 1.43× |

ESP32-S3 compiler inspection confirms four independent native floating-point multiply/add accumulators in the YIN loop; this is not a target timing measurement. The target `Engine` object grows from 14,048 to 20,240 bytes (+6,192 bytes of fixed RAM), primarily for mirrored history. The default application grows from 613,200 to 613,776 bytes (+576 bytes). No dynamic allocation is added to the DSP path.

A local comparison of 12 synthetic two-second streams (four/five strings, both startup profiles, input chunks of 7/32/97 frames) produces identical MIDI bytes, velocity and input-frame event timestamps between 0.2.0 and 0.2.1. Streams include pitch changes, silence and renewed attacks. This does not establish equivalence for all floating-point inputs or real piezo signals.
Raw benchmark and trace comparison outputs are recorded in [desktop-0.2.1.txt](benchmarks/desktop-0.2.1.txt).

### Historical comparison: 0.1.0 to 0.2.0

Reference: the 0.1.0 core from commit `e75defa`; comparison uses the same benchmark source against the original header/implementation.

| Workload | 0.1.0 ns/frame | 0.2.0 ns/frame | Reduction |
| --- | ---: | ---: | ---: |
| One Low B string | 128.4 | 108.4 | 15.6% |
| Five open strings | 353.8 | 281.0 | 20.6% |
| Five strings at fret 12 | 344.3 | 188.8 | 45.2% |
| Five strings at fret 24 | 342.4 | 135.5 | 60.4% |
| Five channels of gated noise | 364.6 | 343.5 | 5.8% |
| Five silent channels | 108.9 | 78.5 | 27.9% |

The muted five-open-string workload is 15.4ns/frame in 0.2.0. This compares skipping pitch work with active pitch work, not an equivalent detection workload.
Noise that never passes the confidence gate continues to be analyzed at the faster startup interval, so its cost reduction is smaller than the tonal workloads in this run.
With the long-startup profile that noise workload measured 295.8ns/frame.
OS preemption/frequency scaling affect these numbers; they do not establish ESP32-S3 CPU headroom or a worst-case execution guarantee.

Run the current benchmark:

```sh
cmake -S firmware/tests -B firmware/build-host -G Ninja
cmake --build firmware/build-host
firmware/build-host/bass_core_benchmark
firmware/build-host/bass_core_benchmark --conservative
firmware/build-host/bass_core_benchmark --muted
```

## Correctness and physical acceptance

Sanitized tests cover equivalence of early-termination YIN to full-lag evaluation across 1500 tonal/noise cases; 720 string cases over frets 0/1/5/12/19/24, phase and amplitude changes with added noise; both tracking profiles; phase discontinuity; muted resume; MIDI packet ordering, endpoint bounds, backpressure and pending-batch discard.
Reconfiguration tests cover invalid construction, rejected slot mappings and four/five-string timing-cache updates in both profiles.
These tests do not execute the physical USB host controller or establish real-piezo detection accuracy.

On M5StickS3, first verify TDM slots/synchronization and USB fixed-note output.
Then run all five strings for at least ten minutes with MIDI and display enabled, checking `dma_ovf`, `queue_drop`, `gaps`, `read_err` and `midi_drop` remain stable.
Observe `queue_peak` and the increase in `dsp_us` against elapsed time. The processing timers include the engine and slot-level calculation; they exclude shared-state publication, USB and LCD, and can include preemption.
Compare startup profiles using recorded real plucks, measuring end-to-end P50/P95 onset time, missed attacks, wrong notes and note-off time.
Test USB host packet batching, disconnect/reconnect, panic, pitch bend and dense event bursts with the actual sound module.

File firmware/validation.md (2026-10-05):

# Firmware validation record

Date: 2026-10-06. Version: 0.2.1. Target: M5StickS3 / ESP32-S3.

## Build

- ESP-IDF v5.4.2, commit `f5c3654a1c2d2a01f7f67def7a0dc48e691f63c0`.
- Espressif Xtensa GCC 14.2.0 (`esp-14.2.0_20241119`), Linux, Python 3.12.
- Standard five-string DSP A / short-startup tracking configuration built successfully. Device and host transports are both compiled into this image; role selection occurs at boot.
- Application: 613776 bytes (`0x95d90`); 3MB factory partition, approximately 80% unused. Version 0.2.0 was 613200 bytes; 0.1.0 was 612032 bytes.
- The four-string Philips / long-startup tracking / separate MIDI channels / Pitch Bend target configuration compiled successfully for 0.2.0; that alternative target build was not repeated for 0.2.1. The current portable-core tests cover four/five strings and both startup profiles. The published binary uses the standard configuration recorded in its `BUILD_INFO.json`.
- Library versions and registry hashes are pinned in `dependencies.lock`.

## Host-side verification

The C++ tests pass with AddressSanitizer and UndefinedBehaviorSanitizer enabled. They cover pitch and note state using synthetic waveforms, four/five independent inputs, slot mapping, arbitrary input block sizes, clipping/noise/DC, velocity, bend, re-picking, failed event delivery, shared-note ownership and separate channels.

Optimization regression tests compare early-termination YIN with full-lag calculation across 1500 tonal/noise cases. Both startup profiles pass 720 string cases spanning fret, phase, amplitude and added noise. Muted resume, sustained-note phase discontinuity and faster startup are covered. Configuration-cache tests also cover invalid construction/reset, rejected duplicate slot mappings and four/five-string reconfiguration in both profiles. A local 12-stream comparison with 0.2.0 preserves MIDI event bytes and input-frame timestamps; details and fixed-RAM tradeoffs are recorded in performance.md. Desktop timing comparisons are recorded separately in [performance.md](performance.md); they do not measure ESP32-S3 execution time.

USB descriptor tests cover MIDI 1.0 OUT discovery, composite interfaces, invalid lengths, truncation, alternate settings, endpoint types/direction and MIDI 2.0 rejection. Packet-batch tests cover event order, 4–64byte endpoint bounds, backpressure and pending-event discard. These test descriptor parsing and portable batching, not physical USB enumeration or transfer callbacks.

The Python offline-calibration tests pass for four/five-channel instantaneous mixing, polarity changes, simultaneous unison, singular matrices, insufficient calibration, clipping and malformed CSV samples. These test the evaluation tool, not the mechanical bridge.

Synthetic open-string first Note On times, each in a one-input configuration: B0 64ms, E1 48ms, A1 40ms, D2 32ms, G2 28ms of input samples. Hardware/transport/synthesizer latency and target CPU execution time are excluded. Five-input schedules have different per-string phases. The long-startup profile measures 80/64/48/48/40ms in the same one-input test.

## Hardware status

No M5StickS3 or assembled Hat was connected for this validation. Flashing, ADC register behavior, cascade slot order, USB device/host enumeration, VBUS adapter compatibility, real-time CPU margin, physical crosstalk and musical performance remain unmeasured. The firmware and binary are evaluation artifacts, and startup defaults to muted.

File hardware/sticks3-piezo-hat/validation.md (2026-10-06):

# R1設計検査

対象：`sticks3-piezo-hat.kicad_pcb`／`sticks3-piezo-hat.kicad_sch`。KiCad 9.0.9。実行日時は各JSONレポートに記載。

| 検査 | 結果 | 記録 |
| --- | ---: | --- |
| PCB未接続 | 0件 | [drc-final.json](drc-final.json) |
| PCB DRC違反・警告 | 0件 | [drc-final.json](drc-final.json) |
| 回路図ERC違反・警告 | 0件 | [erc.json](erc.json) |
| 回路図・PCB・マニフェストの接続一致 | 318接続 | [verification.json](verification.json) |
| SMDパッドとビア穴の重なり | 0件 | [verification.json](verification.json) |
| GND専用内層の信号配線 | 0件 | `release.py`による検査 |
| PCBA BOMとCPLの参照名・実装面 | 101点一致、Topのみ | `release.py`による検査 |

CPLはU3・U4・U5・U6に270°の品番別補正を適用し、D1〜D5をPCBAへ追加。補正一覧と基板上のピン1座標を`release/rotation-audit.csv`に記録する。新しいJLCPCB配置プレビュー、部品照合・調達可否、DFMは未確認。

配線は2410セグメント、161ビア。実部品は表面のみ。裏面はTP1〜TP4の裸銅箔。

`release.py`はDRC／ERC、接続照合、実装面・ビア穴・内層配線の検査を実行し、合格後に製造データを出力する。幾何・接続の検査結果であり、アナログ特性、Hat2嵌合、ADC取得動作、MIDI出力の実機検証は含まない。

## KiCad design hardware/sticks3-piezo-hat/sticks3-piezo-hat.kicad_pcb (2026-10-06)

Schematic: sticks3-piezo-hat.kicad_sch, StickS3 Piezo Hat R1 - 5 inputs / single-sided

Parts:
C1, C2, C32, C33, C43, C44: 100n; C_0402_1005Metric_AssemblyFront; LCSC C1525
C3, C4, C7, C8, C11, C12, C15, C16, C19, C20: 47n; C_0402_1005Metric_AssemblyFront; LCSC C82219
C5, C6, C9, C10, C13, C14, C17, C18, C21, C22, C51, C52, C53, C54: 10u; C_0603_1608Metric_AssemblyFront; LCSC C19702
C23, C24, C25, C26, C27, C28, C29, C30, C31, C34, C35, C36, C37, C38, C39, C40, C41, C42, C45, C46, C47, C48, C49, C50, C55: 1u; C_0402_1005Metric_AssemblyFront; LCSC C52923
D1, D2, D3, D4, D5: BAV199W; SOT-323_SC-70_AssemblyFront; LCSC C51315120
J1: PIEZO1; PiezoPair_P3.8
J2: PIEZO2; PiezoPair_P3.8
J3: PIEZO3; PiezoPair_P3.8
J4: PIEZO4; PiezoPair_P3.8
J5: PIEZO5; PiezoPair_P3.8
J6: HAT2_MANUAL; PinHeader_2x08_P2.54mm_Horizontal_AssemblyFront; LCSC C53207371
R1, R4, R7, R10, R13, R26, R28, R29: 47k; R_0603_1608Metric_AssemblyFront; LCSC C25819
R2, R3, R5, R6, R8, R9, R11, R12, R14, R15: 10M; R_0402_1005Metric_AssemblyFront; LCSC C54531017
R16, R17, R18, R19, R20, R21, R22, R23, R24, R25, R30, R31: 1k; R_0402_1005Metric_AssemblyFront; LCSC C11702
R32, R33, R34, R35, R36: 33R; R_0402_1005Metric_AssemblyFront; LCSC C25105
TP1: GND; TestPoint_Pad_D1.0mm_AssemblyFront
TP2: 3V3A; TestPoint_Pad_D1.0mm_AssemblyFront
TP3: 3V3D; TestPoint_Pad_D1.0mm_AssemblyFront
TP4: VMID; TestPoint_Pad_D1.0mm_AssemblyFront
U1, U2: TLV9064IRTER; QFN-16-1EP_3x3mm_P0.5mm_EP1.675x1.675mm_AssemblyFront; LCSC C882406
U3, U4: ES7210; ES7210_QFN32_4x4_P0.4_EP2.7; LCSC C365743
U5, U6: AP2112K-3.3TRG1; SOT-23-5_AssemblyFront; LCSC C51118

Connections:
3V3A: C1.1, C2.1, C30.1, C31.1, C41.1, C42.1, C52.1, D1.2 (K2/V+), D2.2 (K2/V+), D3.2 (K2/V+), D4.2 (K2/V+), D5.2 (K2/V+), R28.1, TP2.1, U1.2 (V+), U2.2 (V+), U3.22 (VDDA), U3.23 (VDDM), U4.22 (VDDA), U4.23 (VDDM), U5.5 (VOUT)
3V3D: C32.1, C33.1, C43.1, C44.1, C54.1, R26.2, R30.2, R31.2, TP3.1, U3.6 (VDDP), U3.7 (VDDD), U4.1 (AD0), U4.6 (VDDP), U4.7 (VDDD), U6.5 (VOUT)
5V_HAT: C51.1, C53.1, J6.3 (EXT_5V), U5.1 (VIN), U5.3 (EN), U6.1 (VIN), U6.3 (EN)
AIN1N: C6.1, U3.15 (MIC1N)
AIN1P: C5.2, U3.16 (MIC1P)
AIN2N: C10.1, U3.20 (MIC2N)
AIN2P: C9.2, U3.19 (MIC2P)
AIN3N: C14.1, U3.32 (MIC3N)
AIN3P: C13.2, U3.31 (MIC3P)
AIN4N: C18.1, U3.27 (MIC4N)
AIN4P: C17.2, U3.28 (MIC4P)
AIN5N: C22.1, U4.15 (MIC1N)
AIN5P: C21.2, U4.16 (MIC1P)
AIN6N: C46.1, U4.20 (MIC2N)
AIN6P: C45.1, U4.19 (MIC2P)
AIN7N: C48.1, U4.32 (MIC3N)
AIN7P: C47.1, U4.31 (MIC3P)
AIN8N: C50.1, U4.27 (MIC4N)
AIN8P: C49.1, U4.28 (MIC4P)
BCLK: R33.2, U3.9 (SCLK), U4.9 (SCLK)
BCLK_HAT: J6.8 (G7/BCLK), R33.1
BIAS1: R2.2, R3.1
BIAS2: R5.2, R6.1
BIAS3: R8.2, R9.1
BIAS4: R11.2, R12.1
BIAS5: R14.2, R15.1
BUF1: R16.1, U1.15 (OUTA), U1.16 (INA-)
BUF2: R18.1, U1.4 (INB-), U1.5 (OUTB)
BUF3: R20.1, U1.8 (OUTC), U1.9 (INC-)
BUF4: R22.1, U1.13 (IND-), U1.14 (OUTD)
BUF5: R24.1, U2.15 (OUTA), U2.16 (INA-)
CASCADE: R36.1, U3.11 (TDMOUT)
CASCADE_IN: R36.2, U4.12 (TDMIN)
GND: C1.2, C2.2, C3.2, C4.2, C6.2, C7.2, C8.2, C10.2, C11.2, C12.2, C14.2, C15.2, C16.2, C18.2, C19.2, C20.2, C22.2, C23.2, C24.2, C25.2, C26.2, C27.2, C28.2, C29.2, C30.2, C31.2, C32.2, C33.2, C34.2, C35.2, C36.2, C37.2, C38.2, C39.2, C40.2, C41.2, C42.2, C43.2, C44.2, C45.2, C46.2, C47.2, C48.2, C49.2, C50.2, C51.2, C52.2, C53.2, C54.2, C55.2, D1.1 (A1/GND), D2.1 (A1/GND), D3.1 (A1/GND), D4.1 (A1/GND), D5.1 (A1/GND), J1.2 (GND), J2.2 (GND), J3.2 (GND), J4.2 (GND), J5.2 (GND), J6.1 (GND), R29.2, TP1.1, U1.11 (V-), U1.17 (EP/V-), U2.11 (V-), U2.17 (EP/V-), U3.1 (AD0), U3.2 (AD1), U3.8 (GNDD), U3.12 (TDMIN), U3.21 (GNDA), U3.33 (EP), U4.2 (AD1), U4.8 (GNDD), U4.21 (GNDA), U4.33 (EP), U5.2 (GND), U6.2 (GND)
HI1: D1.3 (K1/A2/IN), R1.2, R2.1, U1.1 (INA+)
HI2: D2.3 (K1/A2/IN), R4.2, R5.1, U1.3 (INB+)
HI3: D3.3 (K1/A2/IN), R7.2, R8.1, U1.10 (INC+)
HI4: D4.3 (K1/A2/IN), R10.2, R11.1, U1.12 (IND+)
HI5: D5.3 (K1/A2/IN), R13.2, R14.1, U2.1 (INA+)
INT3: R26.1, U3.13 (INT)
LP1A: C3.1, R16.2, R17.1
LP1B: C4.1, C5.1, R17.2
LP2A: C7.1, R18.2, R19.1
LP2B: C8.1, C9.1, R19.2
LP3A: C11.1, R20.2, R21.1
LP3B: C12.1, C13.1, R21.2
LP4A: C15.1, R22.2, R23.1
LP4B: C16.1, C17.1, R23.2
LP5A: C19.1, R24.2, R25.1
LP5B: C20.1, C21.1, R25.2
MCLK: R32.2, U3.5 (MCLK), U4.5 (MCLK)
MCLK_HAT: J6.7 (G1/MCLK), R32.1
PZ1: J1.1 (SIG), R1.1
PZ2: J2.1 (SIG), R4.1
PZ3: J3.1 (SIG), R7.1
PZ4: J4.1 (SIG), R10.1
PZ5: J5.1 (SIG), R13.1
SCL: J6.2 (G5/SCL), R31.1, U3.4 (CCLK), U4.4 (CCLK)
SDA: J6.4 (G4/SDA), R30.1, U3.3 (CDATA), U4.3 (CDATA)
SPARE_C: U2.8 (OUTC), U2.9 (INC-)
SPARE_D: U2.13 (IND-), U2.14 (OUTD)
TDM_HAT: J6.9 (G8/DATA), R35.2
TDM_OUT: R35.1, U4.11 (TDMOUT)
U3_MICBIAS12: C25.1, U3.24 (MICBIAS12)
U3_MICBIAS34: C27.1, U3.26 (MICBIAS34)
U3_REFP12: C23.1, U3.17 (REFP12)
U3_REFP34: C28.1, U3.29 (REFP34)
U3_REFQ12: C24.1, U3.18 (REFQ12)
U3_REFQ34: C29.1, U3.30 (REFQ34)
U3_REFQM: C26.1, U3.25 (REFQM)
U4_MICBIAS12: C36.1, U4.24 (MICBIAS12)
U4_MICBIAS34: C38.1, U4.26 (MICBIAS34)
U4_REFP12: C34.1, U4.17 (REFP12)
U4_REFP34: C39.1, U4.29 (REFP34)
U4_REFQ12: C35.1, U4.18 (REFQ12)
U4_REFQ34: C40.1, U4.30 (REFQ34)
U4_REFQM: C37.1, U4.25 (REFQM)
VDIV: C55.1, R28.2, R29.1, U2.3 (INB+), U2.10 (INC+), U2.12 (IND+)
VMID: R3.2, R6.2, R9.2, R12.2, R15.2, TP4.1, U2.4 (INB-), U2.5 (OUTB)
WS: R34.2, U3.10 (LRCK), U4.10 (LRCK)
WS_HAT: J6.6 (G6/WS), R34.1

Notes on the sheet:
STRING 1: 20M load / unity buffer / passive two-pole LPF / AC isolated ADC
STRING 2: 20M load / unity buffer / passive two-pole LPF / AC isolated ADC
STRING 3: 20M load / unity buffer / passive two-pole LPF / AC isolated ADC
STRING 4: 20M load / unity buffer / passive two-pole LPF / AC isolated ADC
STRING 5: 20M load / unity buffer / passive two-pole LPF / AC isolated ADC
BUFFERS: U1 A-D = strings 1-4; U2 A = string 5; U2 B = VMID; C/D terminated
DECOUPLING / BIAS / CLOCK TERMINATION / TEST: all pins and nets explicit
ADC3 = address 0x40 / inputs 1-4; ADC4 = 0x41 / input 5 plus unused inputs 6-8

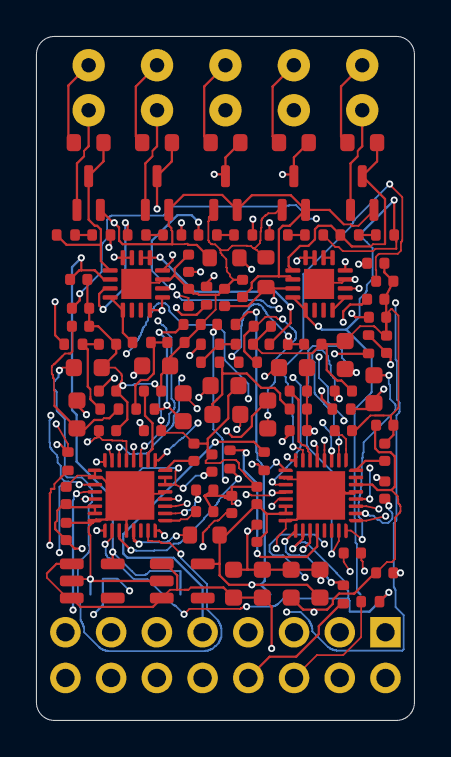
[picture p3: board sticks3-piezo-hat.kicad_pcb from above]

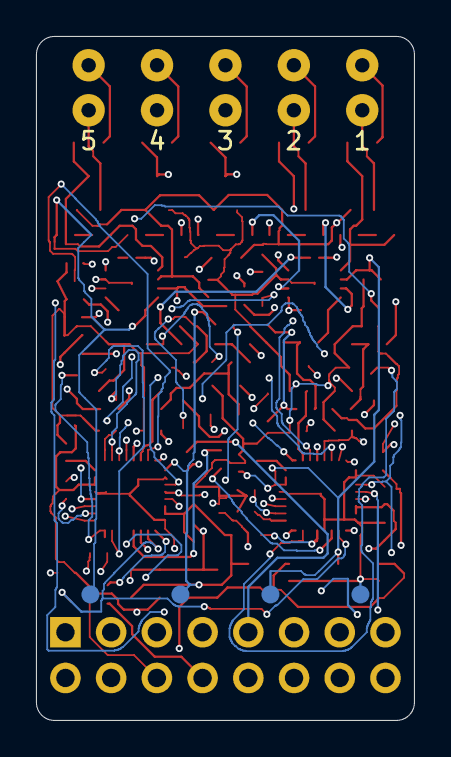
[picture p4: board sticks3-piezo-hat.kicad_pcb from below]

Board: 4 copper layers, 21.0 x 38.0 mm, 111 parts (4 on the bottom side), 81 nets.

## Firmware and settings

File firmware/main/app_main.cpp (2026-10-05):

#include <algorithm>
#include <atomic>
#include <cmath>
#include <cstdio>
#include <cstring>
#include "M5Unified.h"
#include "audio_input.hpp"
#include "bass_core.hpp"
#include "es7210.hpp"
#include "usb_device.hpp"
#include "usb_role.hpp"
#include "esp_check.h"
#include "esp_heap_caps.h"
#include "esp_timer.h"
#include "freertos/semphr.h"
#include "freertos/task.h"

namespace {
constexpr char kTag[] = "bass";
AudioInput audio;
Es7210Pair adc;
UsbDevice usb;
bass::Engine engine(board::config());
bass::MidiRouter router(board::kSeparateChannels, board::kMidiBase);
std::atomic<bool> muted{true}, adc_ready{false}, initialization_done{false};
std::atomic<uint32_t> queue_drops{0}, read_errors{0}, received_blocks{0};
std::atomic<esp_err_t> hardware_error{ESP_ERR_INVALID_STATE};
std::atomic<int> requested_role{-1};
QueueHandle_t audio_queue, controls;
SemaphoreHandle_t status_mutex;

struct Mapping { std::array<uint8_t, bass::kMaxStrings> slots; };
struct Status {
    std::array<bass::StringStatus, bass::kMaxStrings> strings{};
    std::array<float, bass::kSlots> slot_rms{}, slot_peak{};
    bass::Config config;
    uint64_t frames = 0, process_us = 0;
    uint32_t max_process_us = 0, discontinuities = 0, max_queue_blocks = 0;
};
Status status;

class RoutedSink : public bass::MidiSink {
public:
    bool send(bass::MidiMessage message) override {
        return muted.load() || !usb.ready() ? true : router.send(message, usb);
    }
} sink;

void mute(bool value) {
    muted.store(value);
    usb.panic();
}

Status snapshot() {
    xSemaphoreTake(status_mutex, portMAX_DELAY);
    const Status copy = status;
    xSemaphoreGive(status_mutex);
    return copy;
}

void receive_task(void*) {
    AudioBlock block;
    // Discard startup/ADC settling audio before assigning input blocks to DSP.
    for (int i = 0; i < 64; ++i) audio.read(block);
    for (;;) {
        if (audio.read(block) != ESP_OK) {
            read_errors.fetch_add(1);
            usb.panic();
            vTaskDelay(pdMS_TO_TICKS(10));
            continue;
        }
        received_blocks.fetch_add(1);
        if (xQueueSend(audio_queue, &block, 0) != pdTRUE) {
            queue_drops.fetch_add(1);
            usb.panic();
        }
    }
}

void analysis_task(void*) {
    AudioBlock block;
    uint32_t previous_sequence = 0, previous_epoch = usb.epoch();
    bool first = true, previous_mute = muted.load(), previous_ready = usb.ready();
    std::array<float, bass::kSlots> slot_power{};
    uint64_t process_us = 0;
    uint32_t max_process_us = 0, discontinuities = 0, max_queue_blocks = 0;
    uint32_t publish_counter = 0;
    const bool midi_valid = router.valid(CONFIG_BASS_STRING_COUNT);
    for (;;) {
        Mapping mapping;
        while (xQueueReceive(controls, &mapping, 0) == pdTRUE) {
            auto config = engine.config();
            config.slots = mapping.slots;
            if (engine.configure(config, sink)) usb.panic();
        }
        const bool now_mute = muted.load(), now_ready = usb.ready();
        const uint32_t epoch = usb.epoch();
        if (now_mute != previous_mute || now_ready != previous_ready || epoch != previous_epoch) {
            engine.reset(sink, false);
            router.reset();
            previous_mute = now_mute;
            previous_ready = now_ready;
            previous_epoch = epoch;
        }
        if (xQueueReceive(audio_queue, &block, pdMS_TO_TICKS(10)) != pdTRUE) continue;
        max_queue_blocks = std::max(max_queue_blocks, static_cast<uint32_t>(uxQueueMessagesWaiting(audio_queue)));
        const bool gap = block.discontinuity || (!first && block.sequence != previous_sequence + 1);
        first = false;
        previous_sequence = block.sequence;
        if (gap) {
            engine.reset(sink, false);
            router.reset();
            usb.panic();
        }
        const int64_t start = esp_timer_get_time();
        if (engine.valid() && midi_valid &&
            !engine.process(block.samples.data(), board::kBlockFrames, sink, !now_mute && now_ready)) usb.panic();
        std::array<float, bass::kSlots> peaks{};
        for (size_t slot = 0; slot < bass::kSlots; ++slot) {
            float sum = 0;
            for (size_t frame = 0; frame < board::kBlockFrames; ++frame) {
                const float value = block.samples[frame * bass::kSlots + slot] / 32768.0f;
                sum += value * value;
                peaks[slot] = std::max(peaks[slot], std::fabs(value));
            }
            slot_power[slot] += (sum / board::kBlockFrames - slot_power[slot]) * 0.1f;
        }
        // Include level diagnostics in the processing wall-time measurement.
        const uint32_t elapsed = static_cast<uint32_t>(esp_timer_get_time() - start);
        process_us += elapsed;
        max_process_us = std::max(max_process_us, elapsed);
        if (gap) ++discontinuities;
        // UI/CDC need a 16 ms snapshot, not cross-core locking every 2 ms block.
        if (++publish_counter % 8 && !gap) continue;
        xSemaphoreTake(status_mutex, portMAX_DELAY);
        status.strings = engine.status();
        status.config = engine.config();
        status.frames = engine.frames();
        status.process_us = process_us;
        status.max_process_us = max_process_us;
        status.discontinuities = discontinuities;
        status.max_queue_blocks = max_queue_blocks;
        for (size_t slot = 0; slot < bass::kSlots; ++slot) {
            status.slot_rms[slot] = std::sqrt(slot_power[slot]);
            status.slot_peak[slot] = peaks[slot];
        }
        xSemaphoreGive(status_mutex);
    }
}

void console(const char* command, UsbDevice& device, void*) {
    if (!std::strcmp(command, "help")) {
        device.print("help | status | slots | adc | arm | mute | panic | test | role [host|device]\r\n"
                     "map S1 S2 S3 S4 [S5] : unique slots 0-7; not persistent\r\n"
                     "Buttons: A arm/mute, hold A 1s test, B panic, hold B 2s USB role. Test: note 36, 300 ms.\r\n");
    } else if (!std::strcmp(command, "status")) {
        const auto s = snapshot();
        device.print("adc=%s usb=%s muted=%d error=%s blocks=%lu dma_ovf=%lu queue_drop=%lu "
                     "read_err=%lu midi_drop=%lu gaps=%lu queue_peak=%lu max_dsp_us=%lu dsp_us=%llu heap=%lu cdc_drop=%lu\r\n",
                     adc_ready.load() ? "ok" : "error", usb.ready() ? "ready" : "offline",
                     muted.load(), esp_err_to_name(hardware_error.load()),
                     static_cast<unsigned long>(received_blocks.load()),
                     static_cast<unsigned long>(audio.overflows()), static_cast<unsigned long>(queue_drops.load()),
                     static_cast<unsigned long>(read_errors.load()), static_cast<unsigned long>(usb.dropped()),
                     static_cast<unsigned long>(s.discontinuities), static_cast<unsigned long>(s.max_queue_blocks),
                     static_cast<unsigned long>(s.max_process_us),
                     static_cast<unsigned long long>(s.process_us),
                     static_cast<unsigned long>(heap_caps_get_free_size(MALLOC_CAP_INTERNAL)),
                     static_cast<unsigned long>(usb.consoleDrops()));
        for (size_t i = 0; i < s.config.string_count; ++i)
            device.print("J%u slot=%u ch=%u open=%u rms=%.5f hz=%.3f confidence=%.3f note=%d clips=%lu\r\n",
                         static_cast<unsigned>(i + 1), s.config.slots[i], board::midiChannel(i),
                         s.config.open_notes[i], s.strings[i].rms, s.strings[i].hz,
                         s.strings[i].confidence, s.strings[i].note,
                         static_cast<unsigned long>(s.strings[i].clips));
    } else if (!std::strcmp(command, "slots")) {
        const auto s = snapshot();
        for (size_t i = 0; i < bass::kSlots; ++i)
            device.print("slot=%u rms=%.5f peak=%.5f\r\n", static_cast<unsigned>(i), s.slot_rms[i], s.slot_peak[i]);
    } else if (!std::strcmp(command, "adc")) {
        if (!initialization_done.load() || !adc.busReady()) { device.print("ERR ADC bus not ready\r\n"); return; }
        constexpr uint8_t registers[] = {0x02, 0x08, 0x0b, 0x0c, 0x11, 0x12, 0x20, 0x21,
                                         0x22, 0x23, 0x3d, 0x3e, 0x3f, 0x43, 0x4b};
        for (uint8_t address : {board::kAdcA, board::kAdcB}) {
            for (uint8_t reg : registers) {
                uint8_t value = 0;
                if (adc.read(address, reg, value)) device.print("%02x:%02x=%02x\r\n", address, reg, value);
                else { device.print("ERR I2C %02x:%02x\r\n", address, reg); break; }
            }
        }
    } else if (!std::strcmp(command, "role")) {
        device.print("USB role=%s; switch reboots, host needs external VBUS\r\n", device.hostMode() ? "host" : "device");
    } else if (!std::strcmp(command, "role host") || !std::strcmp(command, "role device")) {
        mute(true);
        requested_role.store(!std::strcmp(command, "role host") ? 1 : 0);
        device.print("OK role change requested; reboot; host needs external VBUS\r\n");
    } else if (!std::strcmp(command, "arm")) {
        if (!adc_ready.load() || !snapshot().config.valid() || !router.valid(CONFIG_BASS_STRING_COUNT))
            device.print("ERR ADC/configuration not ready\r\n");
        else { mute(false); device.print("OK armed; MIDI base=%u separate=%d\r\n", board::midiChannel(0), board::kSeparateChannels); }
    } else if (!std::strcmp(command, "mute") || !std::strcmp(command, "panic")) {
        mute(true);
        device.print("OK muted; all sound off\r\n");
    } else if (!std::strcmp(command, "test")) {
        mute(true);
        device.testNote();
        device.print("OK test queued: channel %u, note 36, 300 ms; bass muted\r\n", board::midiChannel(0));
    } else if (!std::strncmp(command, "map ", 4)) {
        const auto s = snapshot();
        auto config = s.config;
        if (!bass::parseSlotMapping(command + 4, config.string_count, config.slots) || !config.valid()) {
            device.print("ERR expected %u unique slots in range 0-7\r\n", config.string_count); return;
        }
        mute(true);
        const Mapping mapping{config.slots};
        if (xQueueSend(controls, &mapping, 0) != pdTRUE) device.print("ERR command queue full\r\n");
        else device.print("OK mapping queued; verify status, then arm\r\n");
    } else device.print("ERR unknown command; type help\r\n");
}
} // namespace

extern "C" void app_main() {
    status_mutex = xSemaphoreCreateMutex();
    audio_queue = xQueueCreate(16, sizeof(AudioBlock));
    controls = xQueueCreate(8, sizeof(Mapping));
    if (!status_mutex || !audio_queue || !controls) abort();
    status.config = board::config();
    auto cfg = M5.config();
    cfg.internal_mic = cfg.internal_spk = cfg.internal_imu = cfg.internal_rtc = false;
    cfg.external_display_value = 0;
    cfg.output_power = false;
    cfg.fallback_board = m5::board_t::board_M5StickS3;
    M5.begin(cfg);
    M5.Display.setRotation(1);
    M5.Display.setBrightness(80);
    M5.Display.setTextSize(1);
    bool host_mode = usb_role::load();
    // Holding A during reset is an unconditional device-mode recovery path.
    for (int i = 0; i < 15; ++i) { M5.update(); vTaskDelay(pdMS_TO_TICKS(20)); }
    bool recovery_press = M5.BtnA.isPressed();
    if (recovery_press) host_mode = false;
    M5.BtnB.setHoldThresh(2000);
    M5.BtnA.setHoldThresh(1000);
    ESP_ERROR_CHECK(usb.begin(console, nullptr, host_mode));
    if (M5.getBoard() != m5::board_t::board_M5StickS3) {
        hardware_error.store(ESP_ERR_NOT_SUPPORTED);
        ESP_LOGE(kTag, "Only M5StickS3 is supported; Hat power stays off");
    } else {
        M5.Power.setExtOutput(true);
        vTaskDelay(pdMS_TO_TICKS(50));
        esp_err_t error = audio.begin();
        if (error == ESP_OK) error = adc.begin(CONFIG_BASS_GAIN_DB);
        if (error == ESP_OK) error = audio.restartCapture();
        hardware_error.store(error);
        adc_ready.store(error == ESP_OK);
    }
    initialization_done.store(true);
    ESP_ERROR_CHECK(xTaskCreatePinnedToCore(analysis_task, "bass_dsp", 8192, nullptr, 17, nullptr, 1)
                    == pdPASS ? ESP_OK : ESP_ERR_NO_MEM);
    if (adc_ready.load()) {
        ESP_ERROR_CHECK(xTaskCreatePinnedToCore(receive_task, "bass_rx", 4096, nullptr, 22, nullptr, 0)
                        == pdPASS ? ESP_OK : ESP_ERR_NO_MEM);
#ifndef CONFIG_BASS_START_MUTED
        if (board::config().valid() && router.valid(CONFIG_BASS_STRING_COUNT)) mute(false);
#endif
    }
    int64_t next_display = 0;
    int64_t reboot_at = 0;
    int pending_role = -1;
    for (;;) {
        M5.update();
        if (!recovery_press && M5.BtnA.wasClicked() && adc_ready.load() && snapshot().config.valid() && router.valid(CONFIG_BASS_STRING_COUNT))
            mute(!muted.load());
        if (!recovery_press && M5.BtnA.wasHold()) { mute(true); usb.testNote(); }
        if (!M5.BtnA.isPressed()) recovery_press = false;
        if (M5.BtnB.wasClicked()) mute(true);
        if (M5.BtnB.wasHold()) {
            mute(true);
            requested_role.store(usb.hostMode() ? 0 : 1);
        }
        const int64_t now = esp_timer_get_time();
        const int change = requested_role.exchange(-1);
        if (change >= 0) { mute(true); pending_role = change; reboot_at = now + 300000; }
        if (pending_role >= 0 && now >= reboot_at) {
            const esp_err_t result = usb_role::save(pending_role == 1);
            if (result == ESP_OK) esp_restart();
            ESP_LOGE(kTag, "USB role save failed: %s", esp_err_to_name(result));
            usb.print("ERR role save: %s\r\n", esp_err_to_name(result));
            pending_role = -1;
        }
        if (now >= next_display) {
            next_display = now + 200000;
            const auto s = snapshot();
            M5.Display.startWrite();
            M5.Display.fillScreen(0);
            M5.Display.setCursor(0, 0);
            M5.Display.printf("M5basspiezohat R1\n%s | %s %s\nADC %s  DMA %lu DROP %lu\n",
                muted.load() ? "MUTED" : "ARMED", usb.hostMode() ? "HOST" : "DEVICE",
                usb.ready() ? "ready" : "offline",
                adc_ready.load() ? "OK" : esp_err_to_name(hardware_error.load()),
                static_cast<unsigned long>(audio.overflows()), static_cast<unsigned long>(queue_drops.load()));
            for (size_t i = 0; i < s.config.string_count; ++i)
                M5.Display.printf("J%u S%u %6.1fHz N%2d C%.2f\n", static_cast<unsigned>(i + 1),
                    s.config.slots[i], s.strings[i].hz, s.strings[i].note, s.strings[i].confidence);
            M5.Display.printf("A arm/hold test B USB\nDSP %lu us HOST ERR %lu", static_cast<unsigned long>(s.max_process_us),
                             static_cast<unsigned long>(usb.hostErrors()));
            M5.Display.endWrite();
        }
        vTaskDelay(pdMS_TO_TICKS(20));
    }
}

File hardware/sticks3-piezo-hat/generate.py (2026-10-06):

#!/usr/bin/python3
"""Generate editable KiCad prototype sources, BOM and connectivity manifest.
Run with /usr/bin/python3 (KiCad 9 pcbnew). Sources remain the design authority.
No claim of measured analogue performance or verified host connector mating.
"""
from pathlib import Path
from collections import defaultdict
import json, csv, math, uuid
import numpy as np
import pcbnew as k

OUT=Path(__file__).resolve().parent
NAME='sticks3-piezo-hat'
LIB=OUT/'PiezoHat.pretty'
LIB.mkdir(exist_ok=True)
ORIGIN=(40,30)
W,H,R=21,38,1
ROOT=str(uuid.uuid5(uuid.NAMESPACE_URL,NAME))
def uid(s): return str(uuid.uuid5(uuid.NAMESPACE_URL,NAME+'/'+s))
def mm(x): return k.FromMM(x)
def pos(x,y): return k.VECTOR2I(mm(x+ORIGIN[0]),mm(y+ORIGIN[1]))
def q(s): return json.dumps(str(s),ensure_ascii=False)

parts={
 'OP':('TLV9064IRTER','C882406','Package_DFN_QFN:QFN-16-1EP_3x3mm_P0.5mm_EP1.675x1.675mm','JLC','check at BOM upload',.8868),
 'ADC':('ES7210','C365743','PiezoHat:ES7210_QFN32_4x4_P0.4_EP2.7','JLC','Extended',.9057),
 'LDO':('AP2112K-3.3TRG1','C51118','Package_TO_SOT_SMD:SOT-23-5','JLC','check at BOM upload',.1726),
 'CLAMP':('BAV199W (CBI)','C51315120','Package_TO_SOT_SMD:SOT-323_SC-70','JLC','check sourcing at BOM upload',.0336),
 'R1k':('0402WGF1001TCE','C11702','Resistor_SMD:R_0402_1005Metric','JLC','Basic observed',None),
 'R10M':('1RC0402J0106','C54531017','Resistor_SMD:R_0402_1005Metric','JLC','check at BOM upload',.0012),
 'R47k':('0603WAF4702T5E','C25819','Resistor_SMD:R_0603_1608Metric','JLC','check at BOM upload',None),
 'R33':('0402WGF330JTCE','C25105','Resistor_SMD:R_0402_1005Metric','JLC','check at BOM upload',None),
 'C100n':('CL05B104KO5NNNC','C1525','Capacitor_SMD:C_0402_1005Metric','JLC','check at BOM upload',None),
 'C47n':('0402B473K500NT','C82219','Capacitor_SMD:C_0402_1005Metric','JLC','check at BOM upload',None),
 'C1u':('CL05A105KA5NQNC','C52923','Capacitor_SMD:C_0402_1005Metric','JLC','check at BOM upload',None),
 'C10u':('CL10A106KP8NNNC','C19702','Capacitor_SMD:C_0603_1608Metric','JLC','check at BOM upload',.0322),
 'HAT':('BXCONN PZ-2.54-2*08-8.5-WZ','C53207371','Connector_PinHeader_2.54mm:PinHeader_2x08_P2.54mm_Horizontal','HAND','not needed for PCBA',.0639),
 'PIEZO':('Internal wire solder pair','','PiezoHat:PiezoPair_P3.8','HAND','board pads only',None),
 'TP':('Test point','','TestPoint:TestPoint_Pad_D1.0mm','NONE','board copper only',None),
}

board=k.BOARD()
board.SetCopperLayerCount(4)
ds=board.GetDesignSettings()
ds.SetBoardThickness(mm(1))
ds.m_MinClearance=mm(.1)
ds.m_TrackMinWidth=mm(.1)
ds.m_CopperEdgeClearance=mm(.5)
ds.m_SolderMaskToCopperClearance=0
ds.m_SolderMaskMinWidth=mm(.10)
ds.m_SilkClearance=mm(.15)
ds.SetCustomTrackWidth(mm(.127))
net={}
def getnet(s):
 if s is None: return None
 if s not in net:
  n=k.NETINFO_ITEM(board,s,len(net)+1); board.Add(n);net[s]=n
 return net[s]

# Custom QFN uses conservative EP geometry common to supplied package revisions.
fp=k.FootprintLoad('/usr/share/kicad/footprints/Package_DFN_QFN.pretty','QFN-32-1EP_4x4mm_P0.4mm_EP2.65x2.65mm')
fp.SetReference('U'); fp.SetValue('ES7210')
fp.SetFPID(k.LIB_ID('PiezoHat','ES7210_QFN32_4x4_P0.4_EP2.7'))
for p in fp.Pads():
 if p.GetNumber()=='33': p.SetSize(k.VECTOR2I(mm(2.7),mm(2.7)))
 p.SetLocalSolderMaskMargin(0)
for g in fp.GraphicalItems():
 if g.GetLayer()==k.F_SilkS: g.SetLayer(k.F_Fab)
k.PCB_IO_MGR.PluginFind(k.PCB_IO_MGR.KICAD_SEXP).FootprintSave(str(LIB),fp)
# Round through-hole wire pads; front-only assembly still allows reverse solder.
fp=k.FOOTPRINT(board)
fp.SetFPID(k.LIB_ID('PiezoHat','PiezoPair_P3.8'))
fp.SetReference('J');fp.SetValue('SIG/GND')
fp.SetAttributes(k.FP_THROUGH_HOLE)
for n,y in [('1',0),('2',2.5)]:
 p=k.PAD(fp);p.SetNumber(n);p.SetShape(k.PAD_SHAPE_CIRCLE)
 p.SetAttribute(k.PAD_ATTRIB_PTH);p.SetSize(k.VECTOR2I(mm(1.8),mm(1.8)))
 p.SetDrillSize(k.VECTOR2I(mm(.8),mm(.8)))
 p.SetLayerSet(k.PAD.PTHMask());p.SetPosition(k.VECTOR2I(0,mm(y)));fp.Add(p)
k.PCB_IO_MGR.PluginFind(k.PCB_IO_MGR.KICAD_SEXP).FootprintSave(str(LIB),fp)
(OUT/'fp-lib-table').write_text('(fp_lib_table (version 7) (lib (name "PiezoHat") (type "KiCad") (uri "${KIPRJMOD}/PiezoHat.pretty") (options "") (descr "Project footprints")))\n')
components=[]; fps={}; counters=defaultdict(int)
def add(ref,key,value,pins,x,y,angle=0,group='misc'):
 mpn,code,fid,assembly,partclass,price=parts[key]
 lib,foot=fid.split(':')
 path=str(LIB) if lib=='PiezoHat' else '/usr/share/kicad/footprints/'+lib+'.pretty'
 f=k.FootprintLoad(path,foot)
 assert f is not None,(fid,ref)
 # Mechanical proxy has the same 3x3 body; exact TLV model is not bundled.
 if key=='OP':
  models=list(f.Models());f.Models().clear()
  for model in models:
   model.m_Filename='${KICAD9_3DMODEL_DIR}/Package_DFN_QFN.3dshapes/QFN-16-1EP_3x3mm_P0.5mm_EP1.7x1.7mm.step'
   f.Add3DModel(model)
 if key=='HAT':
  for pad in f.Pads(): pad.SetDrillSize(k.VECTOR2I(mm(1.02),mm(1.02)))
  # BXCONN drawing: 20.12 +/-0.30 body; 6.9 +/-0.2 + 6.0 +/-0.2
  # from rear hole row to mating tip. Courtyard includes body maximum +0.25.
  # PCB-side occupied area ends at the TH pad +0.25, not a generic proxy margin.
  for g in list(f.GraphicalItems()):
   if g.GetLayer()==k.F_CrtYd: f.Remove(g)
  g=k.PCB_SHAPE(f);g.SetShape(k.SHAPE_T_RECT);g.SetLayer(k.F_CrtYd);g.SetWidth(mm(.05));g.SetStart(k.VECTOR2I(mm(-1.1),mm(-1.57)));g.SetEnd(k.VECTOR2I(mm(13.55),mm(19.35)));f.Add(g)
 # Local footprint variants keep edited fab graphics/mask settings auditable.
 for g in f.GraphicalItems():
  if g.GetLayer()==k.F_SilkS: g.SetLayer(k.F_Fab)
 for p in f.Pads(): p.SetLocalSolderMaskMargin(0)
 dense=foot if lib=='PiezoHat' else foot+'_AssemblyFront'
 f.SetFPID(k.LIB_ID('PiezoHat',dense))
 k.PCB_IO_MGR.PluginFind(k.PCB_IO_MGR.KICAD_SEXP).FootprintSave(str(LIB),f)
 fid='PiezoHat:'+dense
 f.SetReference(ref);f.SetValue(value)
 f.SetPosition(pos(x,y));f.SetOrientationDegrees(angle)
 f.SetPath(k.KIID_PATH('/'+ROOT+'/'+uid(ref)))
 f.Reference().SetVisible(False);f.Value().SetVisible(False)
 f.SetExcludedFromPosFiles(assembly!='JLC')
 f.SetExcludedFromBOM(assembly=='NONE')
 for p in f.Pads():
  n=pins.get(p.GetNumber())
  if n is not None: p.SetNet(getnet(n))
  p.SetLocalSolderMaskMargin(0)
 board.Add(f);fps[ref]=f
 components.append(dict(ref=ref,key=key,value=value,mpn=mpn,lcsc=code,
   footprint=fid,assembly=assembly,part_class=partclass,reference_price=price,
   pins={str(a):b for a,b in pins.items()},x=x,y=y,angle=angle,group=group,uuid=uid(ref)))
 return ref
def passive(prefix,key,value,a,b,x,y,angle=0,group='misc'):
 counters[prefix]+=1
 return add(prefix+str(counters[prefix]),key,value,{'1':a,'2':b},x,y,angle,group)
def cap(key,value,a,x,y,angle=0,group='misc',b='GND'):
 return passive('C',key,value,a,b,x,y,angle,group)
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

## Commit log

2026-10-05 Add M5StickS3 five-channel piezo Hat R1 PCB and fabrication data
    [BOM_JLCPCB.csv, BOM_full.csv, HAND_ASSEMBLY.csv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]
2026-10-05 Implement StickS3 piezo-to-MIDI firmware with USB role switching and calibration tools
    [partitions.csv]
2026-10-05 Retain CAD export attributes alongside third-party notice preservation
2026-10-05 Document fixed Type-C CC resistors and external host connection requirements
2026-10-05 Document Grove UART USB MIDI host expansion and power architecture
2026-10-05 Set native USB host with self-powered instruments as baseline
2026-10-05 Optimize pitch processing loops and data layout for v0.2.1
2026-10-06 Correct JLC placement rotations and include piezo protection diodes in PCBA
    [BOM_JLCPCB.csv, BOM_full.csv, HAND_ASSEMBLY.csv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]
